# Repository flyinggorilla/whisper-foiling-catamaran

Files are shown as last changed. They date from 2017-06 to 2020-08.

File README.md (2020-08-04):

# Whisper Foiling Catamaran sailing experiences

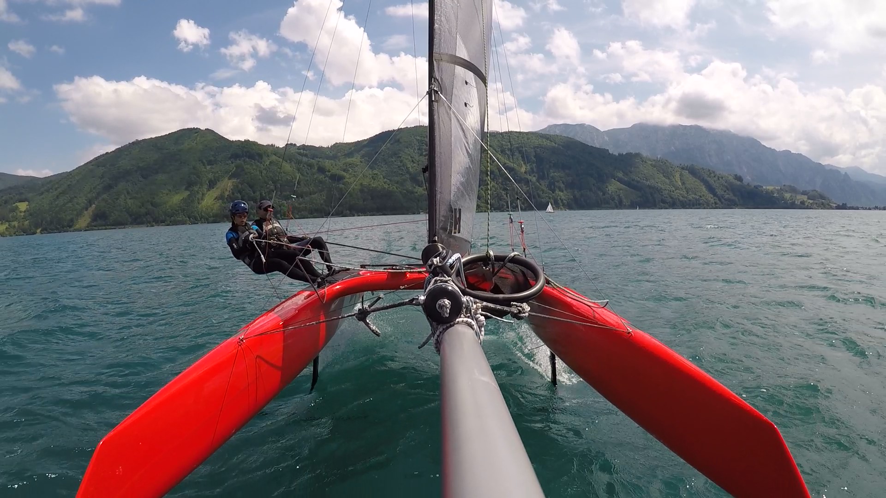
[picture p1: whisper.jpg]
whisper (https://www.youtube.com/channel/UCwhb6u4A_Hy-c-eJbMLW7bg)


# YouTube Whisper Foiling Channel
[YouTube videos](https://www.youtube.com/channel/UCwhb6u4A_Hy-c-eJbMLW7bg)

# Repairing and tuning the Whisper with 3D printed parts
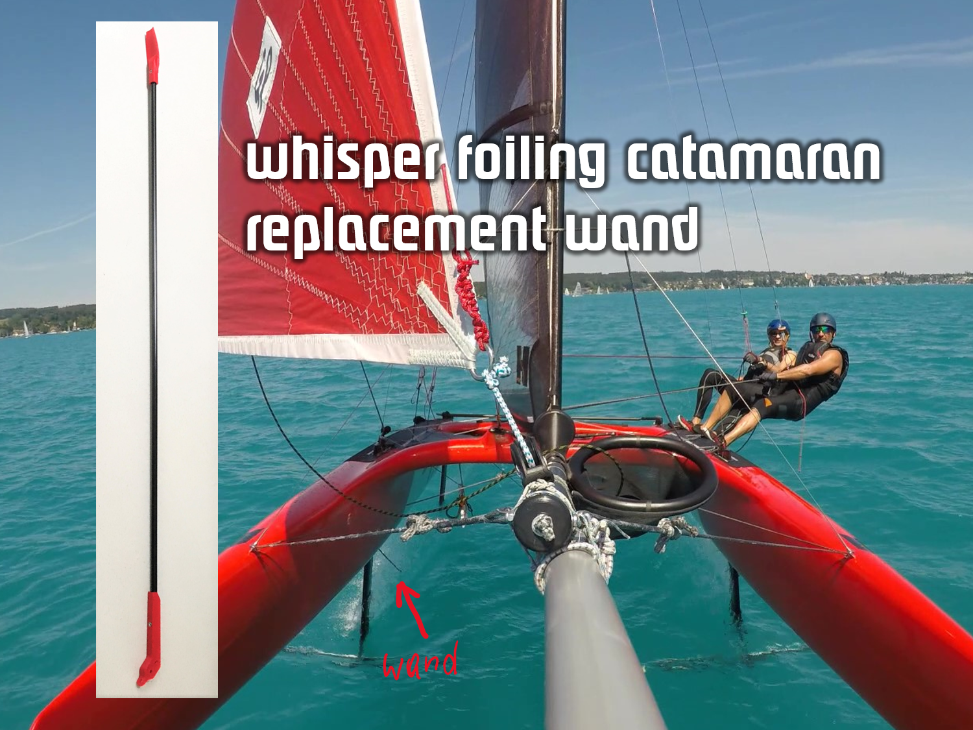
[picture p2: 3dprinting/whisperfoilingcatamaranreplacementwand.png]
3D printing

[3D printed models](3dprinting)

# rigging and trimming tips
## main sail 
O-shackle should be placed in a way that the knot shows towards the mast. This is needed so that the main halyard unhooks easily when rotating the mast 90 degrees.

## foils
Flaps should show 2-3mm upwards when the wands are down.

## Fastest sailing when sail is above one
Async setup of flight height through ride-height adjuster wheel and through foil rake, like 2.5 windwards and 3.5 leewards. 

Foil rake: 4 is absolute max. 2.5 to 3.5 is good.
(Update: I sail in freshwater, which has less density, so I use foil rake at low winds asymmetrical 4 windwards, 5 leewards. When foiling single-handed upwind I go extreme 5 leewards and 2 windwards)

Whiteformula hints: Straight line speed is best upright, but sailing for an upwind mark is best at 15degrees over to windward, this way you will generate lift towards the mark. 
There is no need to adjust the ride-heigth with every tack to achieve the 15 degree angle, just async foil rake and balancing the boat with main sheet should do it. 

## Tacking
I found tacking actually quite tricky with the Whisper vs the Nacra F16. The Whisper barely turns through the wind.
When sailing alone, I keep my weight as far back as possible to turn the bow through the wind. If that doesnt work, whats common, I push the main sail by hand into the wind so the boat gets additional turning momentum.
When sailing with crew, the crew back-winds the jib. However, even this didnt allow for quick tacking. 

The quickes tacking so far is a __semi-foiling tack__. So while on the foils the helm and crew move from trapeze onto the boat. It just needs a little losening the main-sheet and the whisper remains remarkable stable. So then its all about speed of unhooking the trapeze, and turning the boat into the wind while still on the foils. So far we managed twice to turn the boat through the wind. But by then we lost too much speed and went gently off the foils. However, we did the tack in the so far speediest form I know of.  

# boat tweaks

## pressure compensation piece
I modified the hatch lid to have a pressure compensation piece. That is water tight, but also allows air to flow, so that the hull is pressure compensated. I used the Bopla 12mm DAE, one of many vendors. https://www.bopla.de/fileadmin/products/_Product_Information/52042000-spec_DAE_M12_Technische_Information-EN.pdf

pressure compensation

## foot straps
Foot straps are great. No need for a chicken line on downwind course. And especially when single-handed trapezing with gennaker its for me priceless. Yes there is some insury risk, but so far I had not a bit of an issue, as the whispers wavepiercers carve so gently through the water so that you are not thrown off as with a regular catamaran (like my previous F16). I mounted it just about 3 centimeters away (aft) from the internal hull structure you can see when you take a picture with your phone camera from the inside.
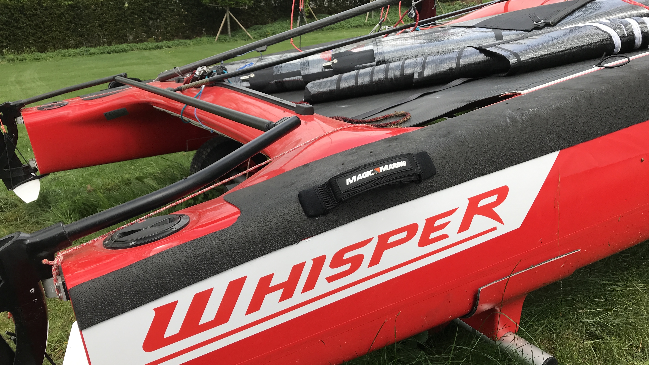
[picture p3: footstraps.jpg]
footstraps

I bent washers to approximate the hull shape and used sealing glue to tighten it 4 screws per strap.

## chicken line
Update: I no longer use the chicken line, as i mounted footstraps. 

So far all of the capsizes and most of the splashes were related to losing balance on the boat. While I hope to get better at keeping balance and steering the boat smoother, I still need to be able to hold-on to something. The traveller line isnt ideal, as the traveller cleat opens to easily and when the traveller is a bit out, you pull the sale all the time. On my Nacra 16 I had a chicken-line, which saved me a couple of times from capsizing when sailing gennaker downwind. So here is my first implementation of a chicken line for the whisper. Its good, it works, and it could be further improved too.
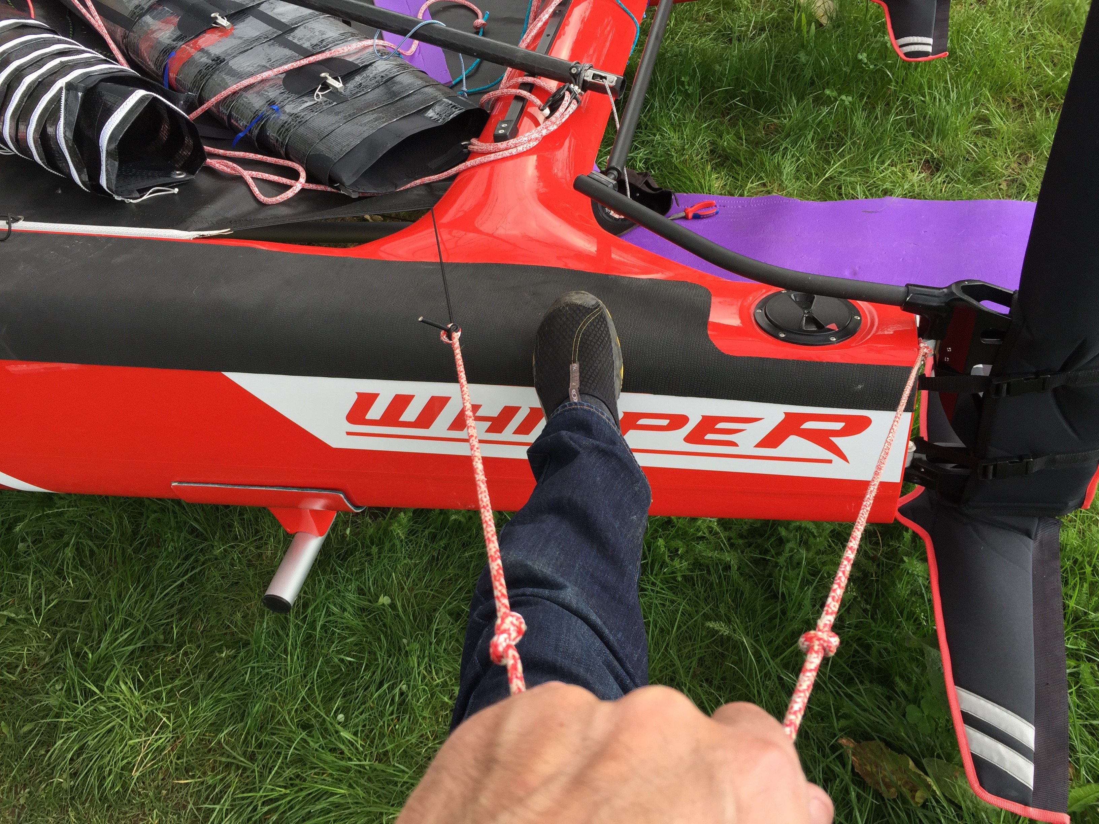
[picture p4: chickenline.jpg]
chicken line


## hull lid marks
Trying to be a "good customer" I followed the advice to untighten the hull-lids - just a little bit by a half turn - so that the hull can equalize air pressure. However, on my third sail with this boat ever, I didnt notize during the pre-sail check that I forgot to tighen it. The lids were on, but just not tight. During a later capsize I lost then one of the hull-lids and flooded one hull with water. The Whisper almost sank and needed some rescue help. So to avoid this from happening ever again, I put a marker on the hull lid, so one can easily see whether its tight or not.
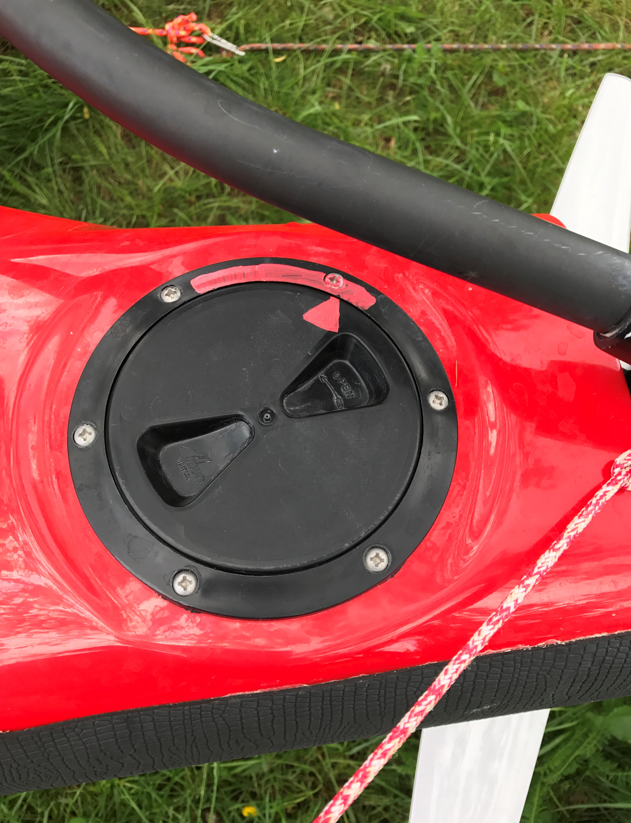
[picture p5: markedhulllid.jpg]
hull lid marks


## 4-wheel trolley
So I do need a 4-wheel trolley to slip the whisper. The air-filled wheels swim nicely. But also they swim nicely, so risking to damage the foils when sliding the boat onto the trolley. So the best fix for this was to fill the rear wheels to almost 100% with liquid. The front wheels got only 50% liquid, so they would still swim, making it easier to keep it in contact with the hulls. I found from the camping area ecological frost proof liquid that is used for camping cars. It felt I filled the old airpump 1000x with that liquid and pressed it into the tyre. But it worked.    
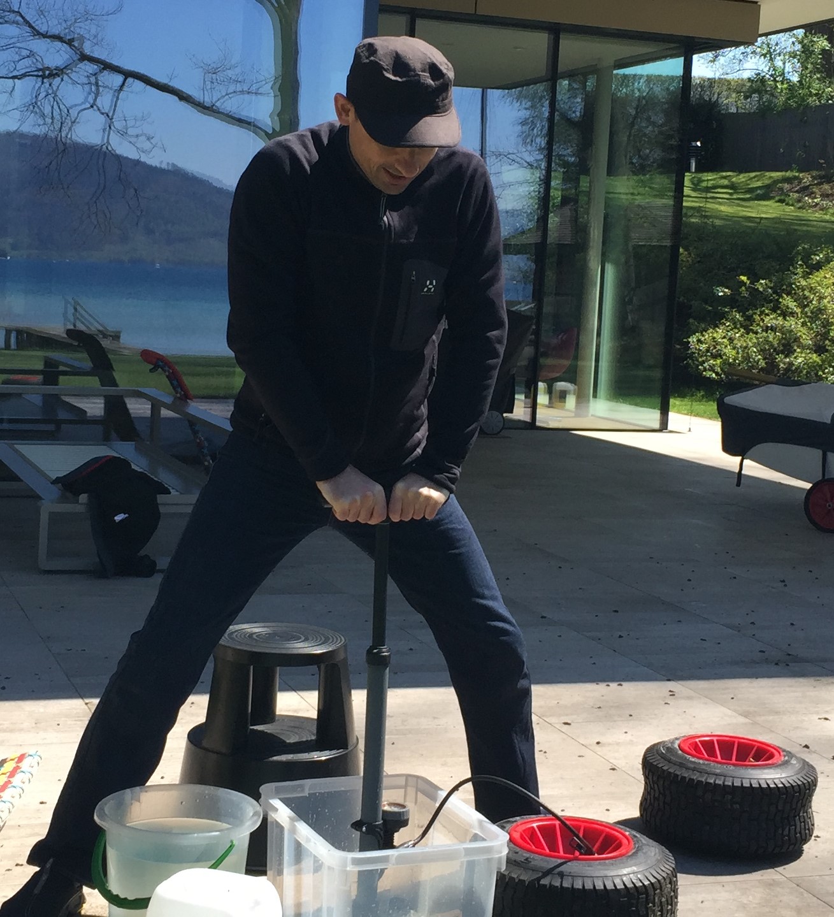
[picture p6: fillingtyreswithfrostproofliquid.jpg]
Sinking wheels

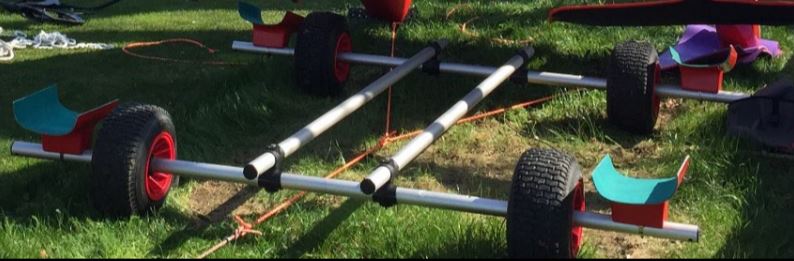
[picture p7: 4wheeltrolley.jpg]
4 wheel trolley


## slipping line
I do slip boats with a winch. I found the best way to pull the Whisper is a dyneema line from the gennaker shackles on each side of the boat. I put a "cleanup" expansion cord in there so its not loose during sailing. slip line

## sacrificial halyard - no longer
At the very first day with the Whisper we lost the jib halyard twice, requiring to pull down the mast. Also I wanted to minimize the amount of work to (de-)rig the Jib.
My solution for this is to have:
* 1.8mm line, about 2m longer than the original sacrificial halyard.  
* tied on one end to the halyard eye
* tied on the other end to my abovementioned slipping line
So when hoisting the Jib, everything stays tied. I simply flake the new (non-)sacrificial halyard and stow it in the trampoline bag. Again, with all knots in place.

Picture shows the (non-)sacrificial halyard tied with a mini-carabiner (not required) to the slip line. 
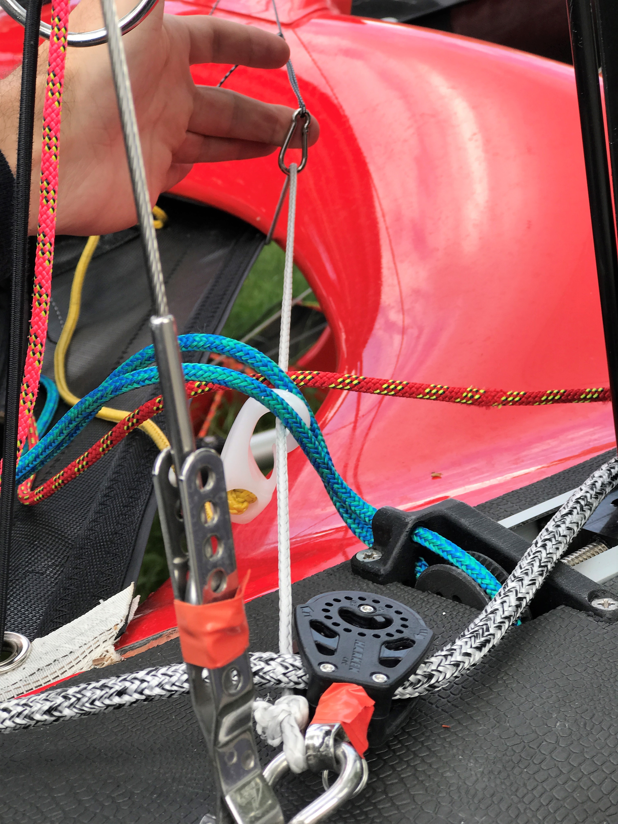
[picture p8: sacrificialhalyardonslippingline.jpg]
sacrificial halyard on slip line


## rigging tension 
Tightening and loosening the rig at the stainless striker with the spanner wrench is somewhat annoying. 
I am a lazy person - in the sense of repetitive tasks - and hence want to automate everything as much as possible.
So I have ordered a 17mm spanner ratchet and let you know how much of a help it is.
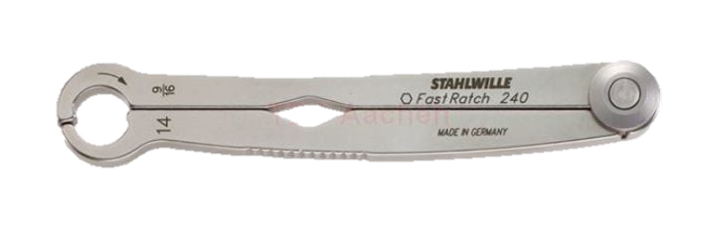
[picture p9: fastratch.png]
fastratch


The Whisper manual says it should be 17 Loos gauge rigging tension. I justs bought a more modern spinlock from rig-sense. There is a [conversion table to loos](https://www.spinlock.co.uk/uploads/files/042018/5acf32f42921105789bbdb1f/original/Spinlock_Conversion_Chart.pdf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) so my mast support rig with 120kg / 21loos should be fine.

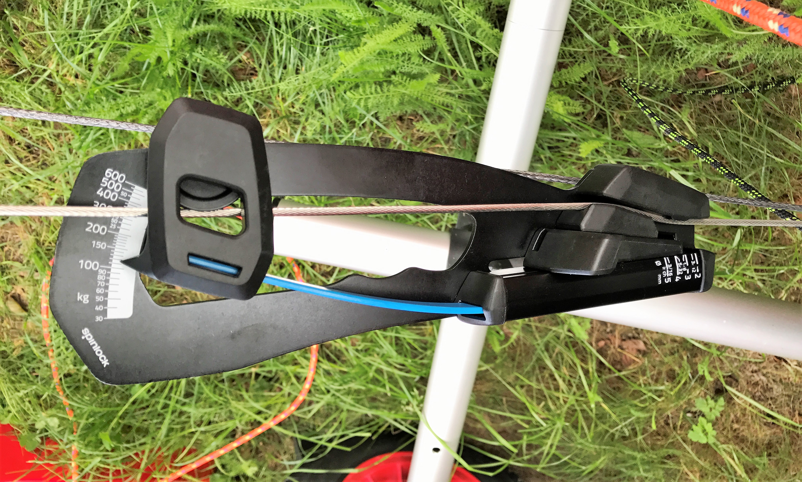
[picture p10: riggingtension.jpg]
rigging tension diamond


Here are some measurements of status quo measurements. I am interested in the appropriate target settings...

| Line | Tension in kg | Loos gauge PT1 (approx.) | comment |
|---|---|---|---|
| Mast support at spi pole 3mm | 160kg+ | ~25  | measured below spi pole |
| Mast support V-wire 3mm | 80kg | ~17 | (V-wire) measured under trampoline, is always half of measured below spi-pole - recommendations seem to be Loose Gage 17 absolute min, 20 light winds, 25 heavier winds on Loos gauge |
| Shrouds 3mm | 80kg  | ~17 |  |
| Diamond 3mm | 125kg  | ~22 |  Should be more Loose 30, which is more 220kg |
| Diamond pre-bend | ~50mm | | measured distance from mast to hypothenuse of triangle |
| Jib | 70kg  | ~15 | measured above stainless striker |

### mast safety line
In order to avoid the mast falling accidentally when untightening the rigging tension at the stainless striker, I put a short piece of dyneema rope there. I am lazy and thats more convenient than tying the spinnaker halyard back and forth to secure the mast.
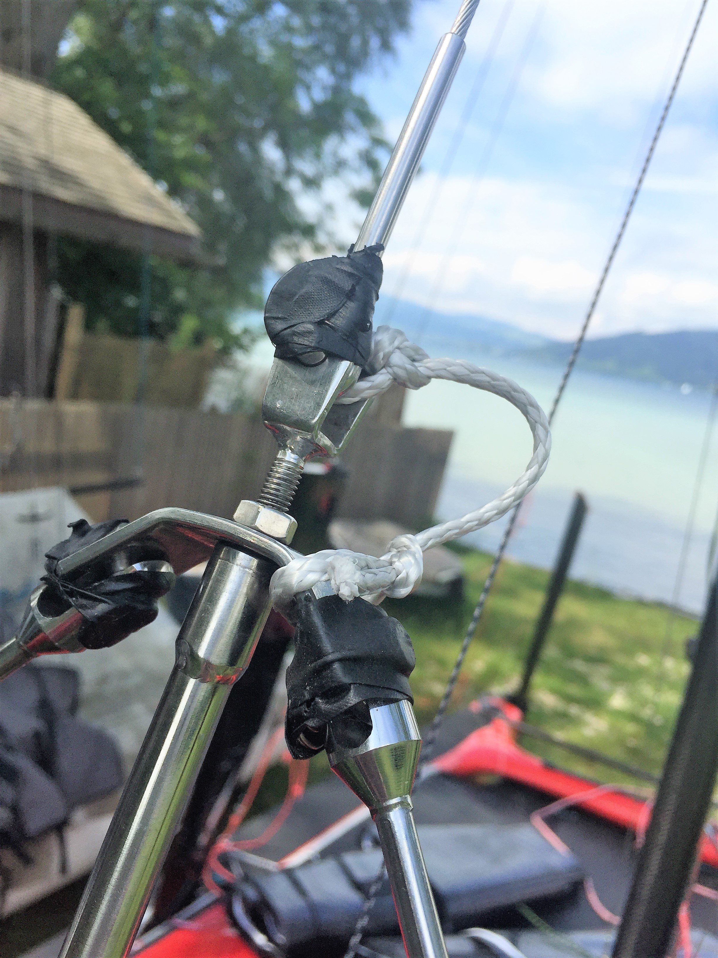
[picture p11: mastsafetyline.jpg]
mast safety line


## ride-height adjuster
I got my stunning looking new black foils and opened the sailing season with them. During one of the first sails I discovered that the ride-height adjustment wheel got looser the more I turned it back and forth. I was worried the mechanics fall apart while on water. So I aborted the sail and took the ride-height system on land apart. The issue was the the **nut on the threaded rod was loose** (see picture below the not on top of the red T). 
I checked the position of the nut so that the 3D-printed wheel would fit nicely, marked the position, and put then __threadlocker glue__ on it to make sure it wouldnt move again. So far it works well. 

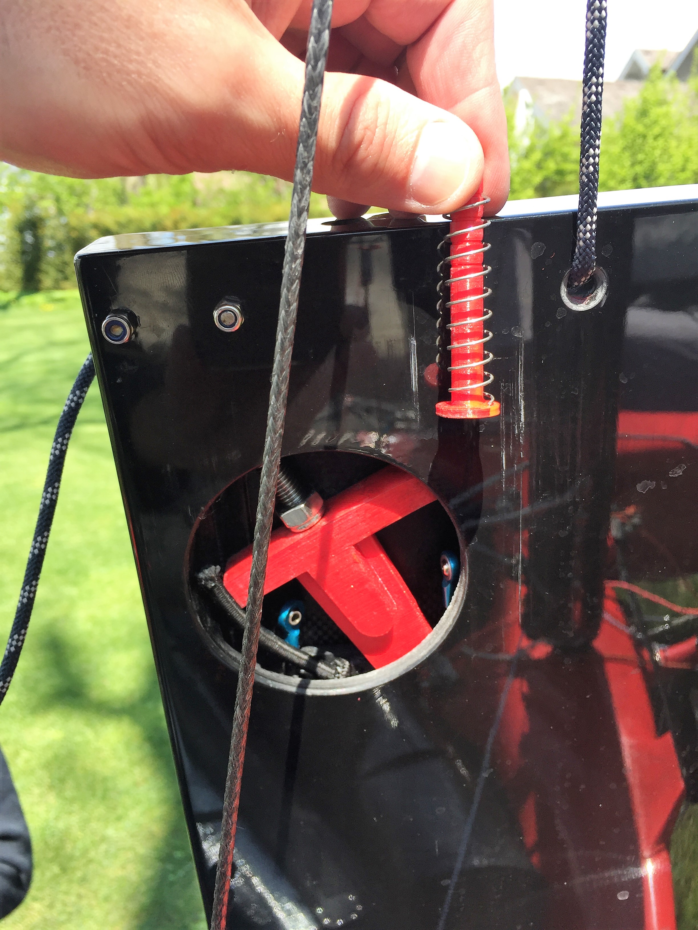
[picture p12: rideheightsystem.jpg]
ride-height system


## righting line
Yes, it costs a few grams, but its less stressful if you have a righting line that you can pull out of the pocket vs. making knots into the gennaker sheet for uprighting. The other benefit is that the crew can use it to hold on when the helm is working the main sheet. 

## main sheet pulley

### 1) two-handed
There is quite some force on your hands when constantly operating the main sheet to balancing the boat on the foils. So I ordered 40mm Harken blocks that allow for a 6:1 translation vs. default 4:1. I also ordered a variable thickness main sheet and need to splice it on the block properly so to not destroy the original pulley. I will let you know how it goes.

6:1 pulley

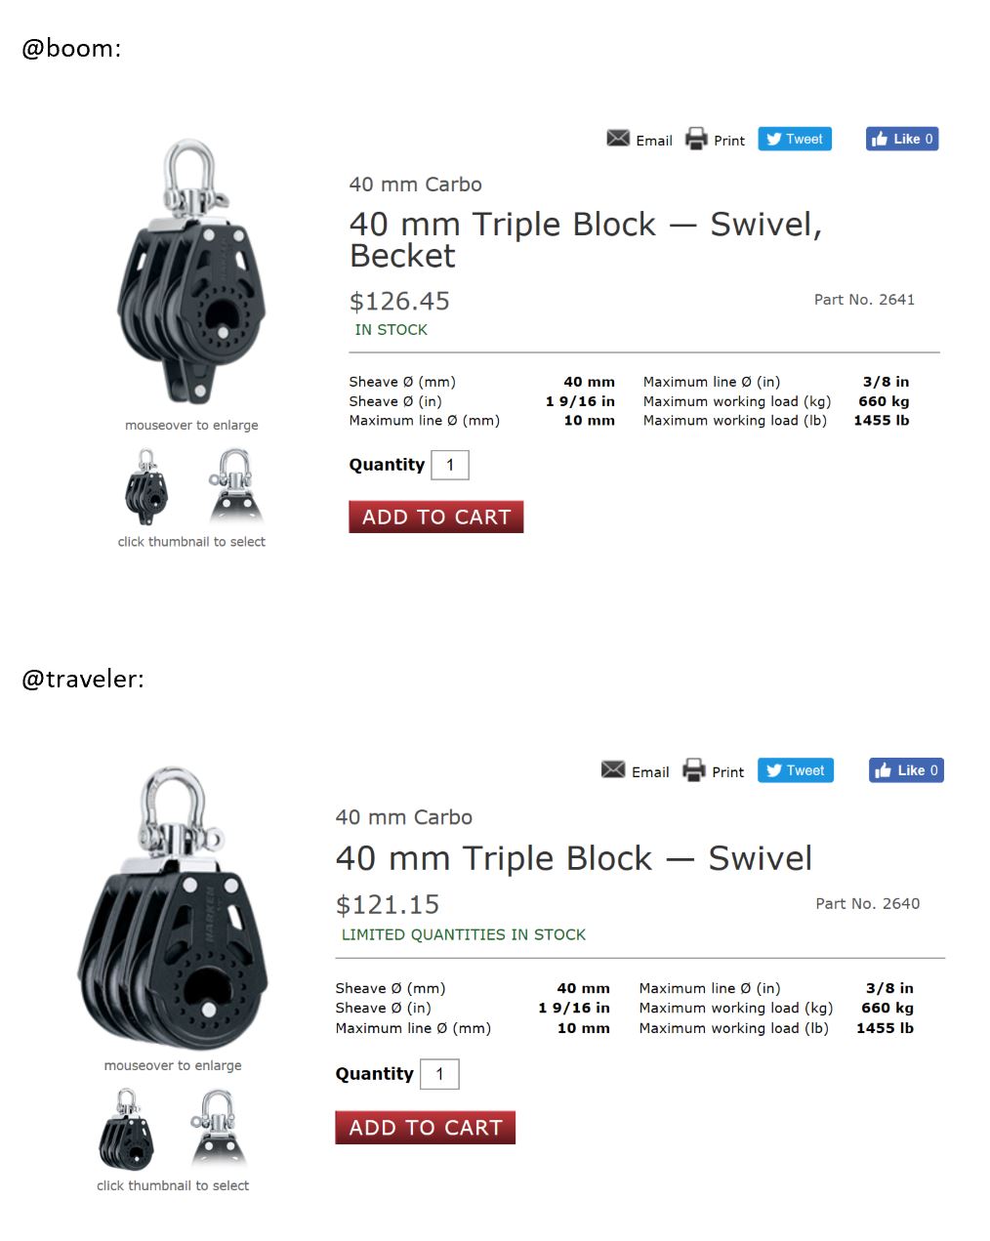
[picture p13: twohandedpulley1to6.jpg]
Harken blocks for two handed 1:6 purchase system


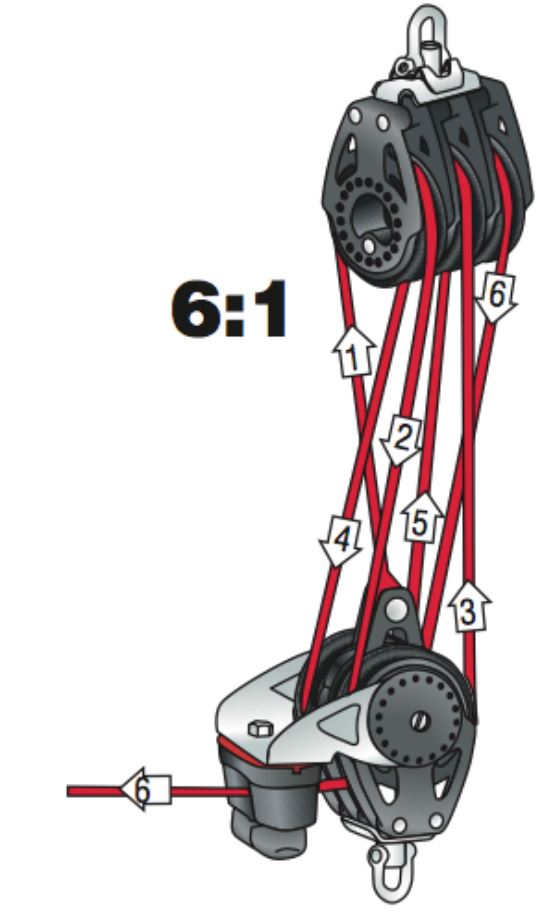
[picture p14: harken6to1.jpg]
harken 6:1


### 2) single-handed
There are two issues making single-handed sailing more difficult. 
* One is that the main-sheet location at the boom,pulls you forward, which makes it hard to balance when you are already hiking at the very end of the boat. 
* Second, managing the gennaker sheet, main sheet and tiller all at once is one thing too much. At the Nacra i could cleat the main sheet while hiking and operating the gennaker.

So the idea is to solve both items with a set of following Harken blocks. I had to take the larger 57mm blocks because the cleats that fit the original block size would only handle 6mm lines, what is too tight for main sheets.
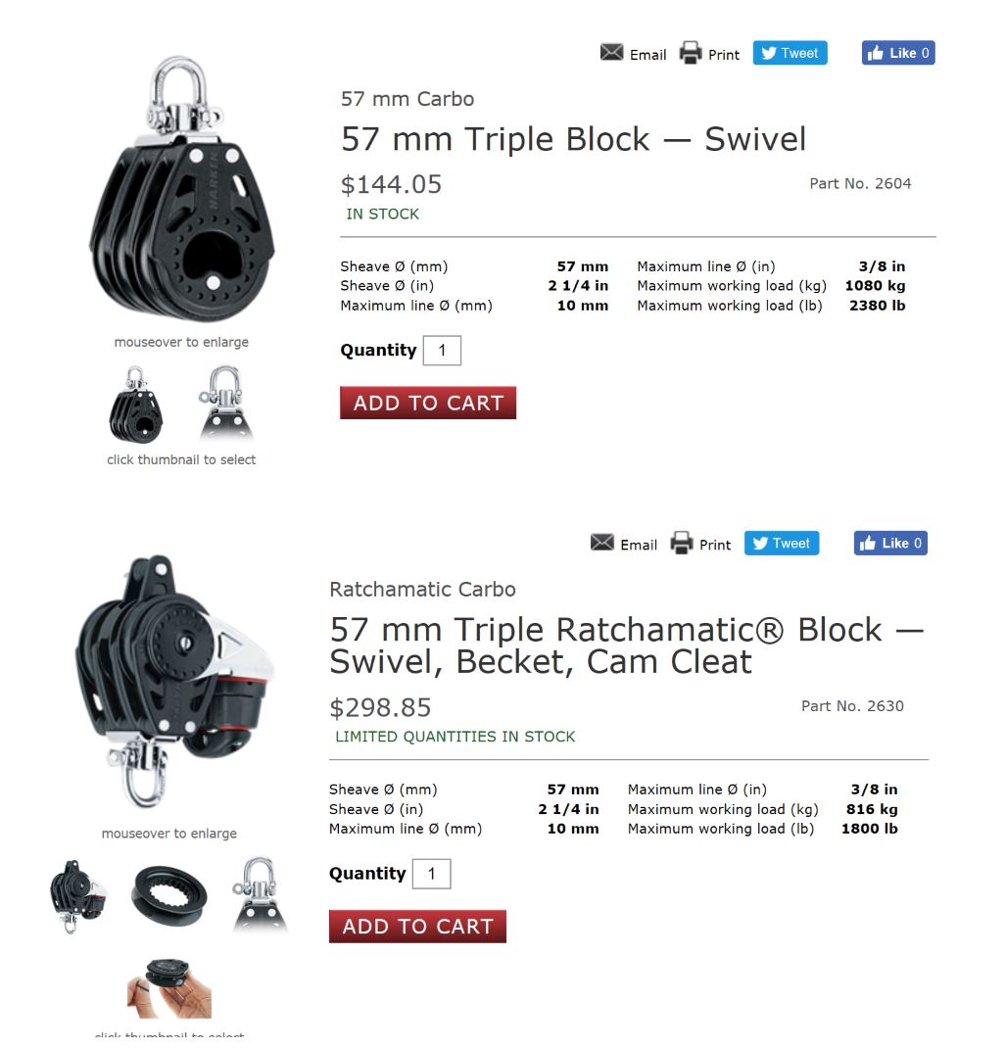
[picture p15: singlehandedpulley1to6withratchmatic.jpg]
Harken 57mm blocks


Yet to be tested.
 
## gps
Having the only whisper at this lake is cool, yet suffers from the ability to match-race. So I need to know the speed on the go, to get a better sense what works. So far my conclusion is that proper boat balance has more impact than sail trim of jib sheet, mast rotation, cunningham. However, I am sure I still need to learn a lot.
So I mounted a Velocitek SpeedPuck. 
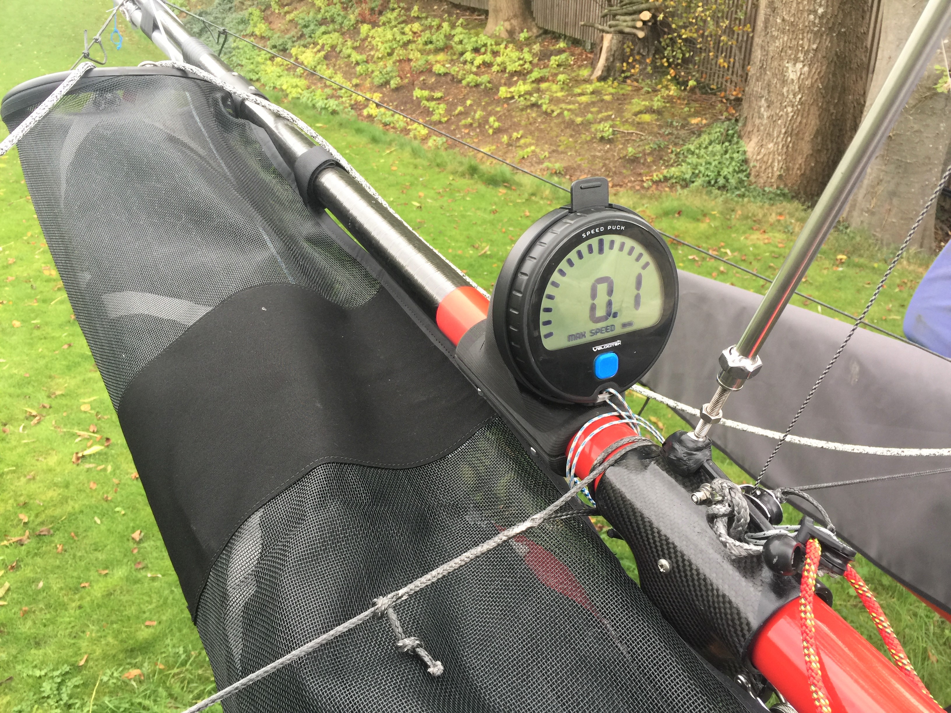
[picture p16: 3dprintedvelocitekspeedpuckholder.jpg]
Speedpuck mounted on Whisper spinnaker boom

The holder is 3D printed and can be found here [https://www.thingiverse.com/thing:1814601](https://www.thingiverse.com/thing:1814601).  
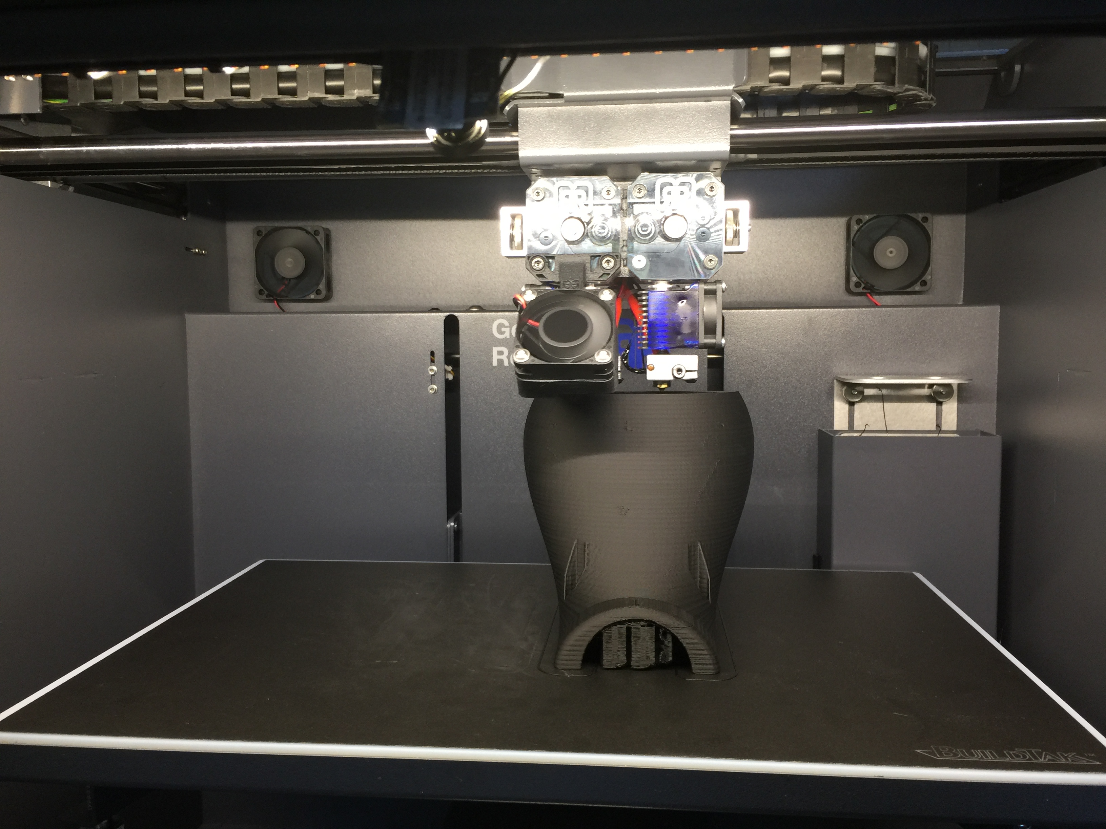
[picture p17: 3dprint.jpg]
3d printed holder


## rudder holder (v1 sucks, better move on to v2 below)
Launching the boat in shallow water requires to hold the rudder in position by hand. When sailing single-handed its impossible to pull the boat at the bow through the water and hold the rudder at the far distant end of the boat at the same time. so something needed to keep the rudder a quarter-height down. I had this door wedge at home, and squeeze this at the side of the rudder to keep it at height. This works ok, when pulling the boat, but as soon as you are on the boat and pick up speed, it falls off as the rudder gets lift. Yes, if you manage to better adjust the angle of the rudder so the force goes down, maybe its possible to better keep it in place. However, I had to dive for the wedge already and since added a line to it.

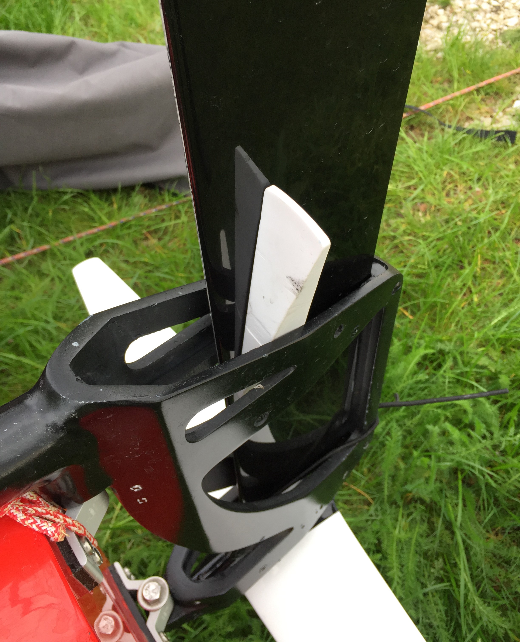
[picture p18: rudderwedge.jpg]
rudder wedge


However, it works only when there are no waves. Waves push the rudder up/down and the wedge falls immediately off. Has anyone a better solution?

As alternative I am thinking about a rope from the T of the foil to keep it up, and another rope from top of foil to keep it down. Maybe 3D print a little piece that makes that easy. So the work on a boat never ends...

## rudder holder (v2 works great)

For coming in/out of shore in shallow waters, I needed a simple solution for keeping the rudder in middle position. One of the issues with my previous "door wedge" solution was that it failed when a wave or simply the foil-lift at speed pushed the rudder up. So the solution needed to keep the rudder in place - up and downwards. Also it should be easily adjustable on the water, without needing to change knots or using tools. So I came up with this simple solution that everyone can 3D print. You need a 3mm rope, a simple plastic carabiner, a 5mm bungee and one or two pieces of those "rope twisters" as I call those 3d printed parts - per rudder you want to equip with this.  
Here is the link to the rudder holder 3D print piece https://www.thingiverse.com/thing:2426782. 

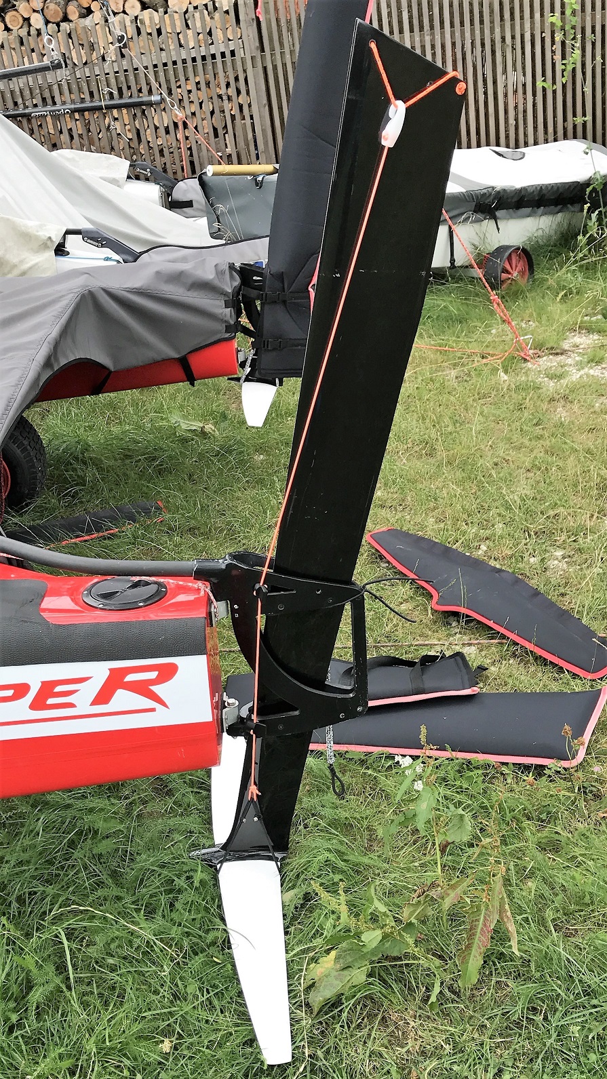
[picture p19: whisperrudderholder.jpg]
whisper rudder holder v2


## repairing the wand

ordering a replacement wand from whiteformula is no problem and reasonable priced. however, as I like to be able to fix things right away and tinker around too, I printed my own wand parts. Ordering carbon rods is no problem too, they are about €10 per piece. 

I have uploaded the [CAD and 3D print models here...](https://www.thingiverse.com/thing:3054149) 
3D Model (https://www.thingiverse.com/thing:3054149)

## how to remove water from the mast
The mast should be water tight. But however, in my unfortunate case when I lost the lid of the hull and the boat almost sank, I did get water into it. The entire mast was in the water and it could have gottin in at the foot or somewhere else on the mast. Usually when capsizing the foot is above water, so less risky for untighteness.

However, in case you have water in the mast, I had gotten from whiteformula's Tom White great hints. To get it out you can remove the screw from the halyard turning block eye. Near the base of the mast. This should let out any water. Note, the smaller upper-one screw of the two is connected with the hollow area of the mast, so this one lets water come out. 

drain water from mast foot

If this does not solve the problem it is most likely that one of the rivet plugs is leaky. You can remove the white plastic plugs in the rivets on the mast hook. You can either pull them out with a pin or you can remove them with a 2.5mm Drill bit. I got some plugs from the nice guys from whiteformula.

drain water from mast top
 
A very easy way to find the leak is to put soapy water over all of the rivets and blow air into the mast through the halyard eye hole using a bike pump. You will see bubbles come from the rivet that is leaky.
 
If it is not a rivet but a screw in the foot, you can remove the screw, put a little silicone in the hole and then put the screw back in. That should solve it.

## water in the hull
Recently, when checking the hull lid, i figured my whisper has water in the hull. I dried it up and after the next sail I had again about half a litre in each of the hulls. Since i didnt capsize i figured the problem must exist on both hulls. So with the lessons learnt from sealing the mast I used soap-water on the outside and my electric airpump (low pressure, vacuum cleaner like pump with 2000l per min throughput) to put a little pressure into the hull. And voila the bubbles revealed that both of the rudder fixings were no longer tight. 
untight rudder mount
According to whiteformula does the urethane based sealant on the pintle always work loose after a while. So this requires re-sealing every year as the load on the transom is very high. 
So I sealed it with flexible silicone and will see how long that lasts. Right now the hull is watertight again.

# some stories...

## swimming for screw-driver
It is not the worst, but still this is what you don't want to happen. Especially when single-handed sailing you are toast. 

So recently we went out, had a great sail. When approaching the shore and stopped to prepare for slipping we couldnt lift the backboard foil anymore. We double-checked the boat speed, but it was zero. So was the wand blocked by a branch or so? Nothing there that we could identify from the trampoline of the boat. Big problem, because it means we cannot pull the boat to the shore due to shallow knee-deep water. 
So we tied the bow to a closeby buoy and I jumped into the 14 degree celcius warm (!) water perform a closer inspection. Then i could feel it with the fingers. There was something on the back side of the foil preventing to lift it. Swimming to the inside of the hull and diving  the head underwater I could see that the screw was loose. Since I usually don't bring my tool-chest on-board flying, I had to take a swim and get a screw driver.Screw tightend and the foil went up again. Phew. Somehow at the end I broke the wand. How that happened is unclear to me. It just broke by a simple touch. Maybe the wand was already damaged during the ride by only being half mounted.
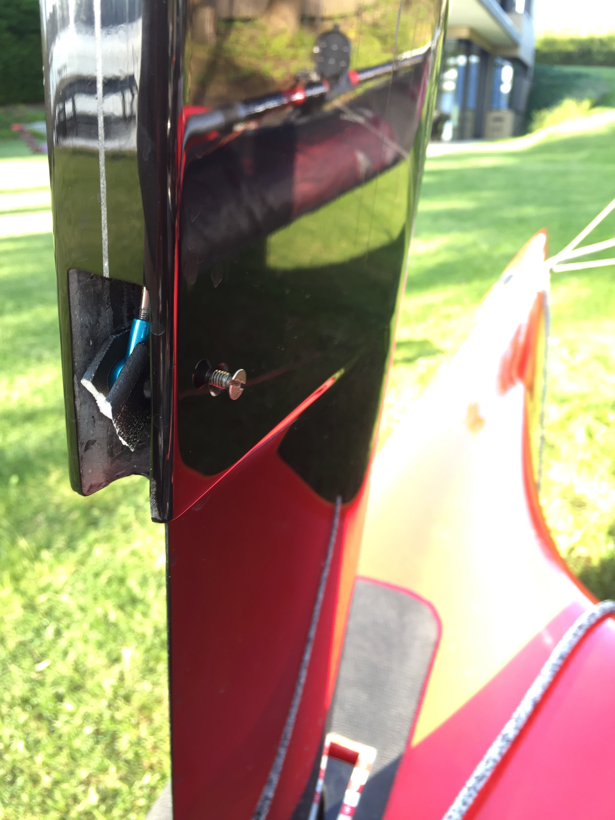
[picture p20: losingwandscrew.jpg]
losing the wand screw


So the boat and crew was rescued and we could slip the boat on land. Gladly I had ordered spare wands with the boat so I was on to fixing that broken one. It was trickier than I thought. The connecting metal axle had to be unscrewed at the top of the foil as well as at the wand. When I had finally the new wand in position, I figured the 3mm screw wouldnt go in. Why? There were no threads. So fortunately I had 3mm thread cutting bits. They come as a set of 3 and I used only the first two, so that the threads would be tight enough and keep the screw in place.

As to the larger screw that I almost lost during sailing, I used silicone glue, which should allow me to open the screw again in the unpleasent event i crack the wand again.

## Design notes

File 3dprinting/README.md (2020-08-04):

# Repairing and tuning the Whisper with 3D printed parts
3D printing

* [__wand system__](#Wand-System) to replace parts that break with easier access as well as tunings
* [__ride height adjuster__](#Ride-Height-Adjuster) much easier than the rope, with up/down indicators
* [__rig tension adjuster__](#Rig-Tension-Adjuster) stainless striker hand-wheel
* [__rudder holder__](#Rudder-Holder) to lock in various heights in shallow waters
* [__speedpuck mount__](#Speedpuck-Mount)

community contributions:
* [__boom holder__](#Boom-Holder)
* [__dolphin striker line guide__](#Dolphin-Striker-Line-Guide)

# Wand System
The [Whisper foiling catamaran](https://www.youtube.com/channel/UCwhb6u4A_Hy-c-eJbMLW7bg) uses "wands" as ride height sensor to dynamically control the foil lift. Parts of that wand system break from time to time, so printing them yourself can be convenient.

To produce an entire wand, you do need:
--------------------------------------------------------
* carbon rod (CFK) 8mm diameter, 1m length (you will need to cut it to 830mm length)

* 3D print paddle (lower end)
* 3D print arm (top part of wand)
* 2 stainless screws (3mm x 10mm or longer) -- you will clip to proper length anyway

Print material needs to be stronger than PLA, so I use e.g. ASA instead..

additional replacement parts related to the wand system:
--------------------------------
* lever inside of foil ride height mechanism

### Updates:
* 20180826: updated wand arm to mount the rod screw from the side
* 20200530: added wand paddle/skimmer model with screw mounting from aft
* 20200530: added wand paddle/skimmer model with screw mounting side - maybe thats the most convenient option for mounting. 
* 20200606: added wand arm version to mount the rod screw from aft, and another version to mount the screw from both sides, to make unmount/mounting easier. mechanically is the version from 2018 with one rod screw from side more robust.

## wand arm:
* use 8mm drill to create a snug fit of the rod into the 3D printed parts
* drill 5mm hole for the shock cord that pulls the arm back
* drill 4mm hole for the hinge
* drill 2.5mm holes for the metal connector, and cut a M3 3mm metric thread into it 
* drill a 2.5mm hole into the carbon rod for the 3mm screw (I use a HSS-cobalt drill for the Carbon rod)
* clip the screw to a length so it just doesnt stand out on the other side of the arm

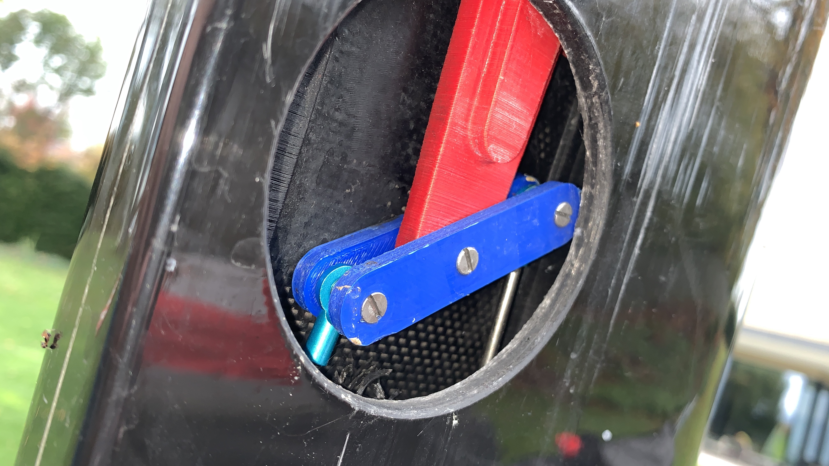
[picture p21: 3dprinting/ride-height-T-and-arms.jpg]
arms

note: picture shows original whiteformula printed red T-part which was printed standing. thus you see the printing layers. this part will break easily therefore. read below how to print stronger T-parts. The blue arms are printed with strong ApolloX ASA material.

## wand paddle:
* use 8mm drill to create a snug fit of the rod into the 3D printed parts
* drill a 2.5mm hole for the 3mm screw (I use a HSS-cobalt drill for the Carbon rod)
* clip the screw to a length so it just doesnt stand out on the other side of the paddle

## wand rod:
* total length of original wand including arm and paddle is 930mm
* cut the carbon rod to 830mm 

## wand ride height lever:
* drill 2.5mm holes for the 3mm screws (I use a HSS-cobalt drill for the Carbon rod)
* drill 2.5mm holes for the connecting rod
* cut M3 3mm metric thread into it -- you might use only 2 of three cutting tools, so that the fit of the screw is tighter
* a tiny bit of glue helps additionally to lock the screws, so they dont open accidentally 

## wand T part:

This is a replacement part for the Whisper foiling catamarans ride height T part. It is printed laid down so to benefit from increased strength vs. the original part. As a tradeoff, it needs to be printed with supports.

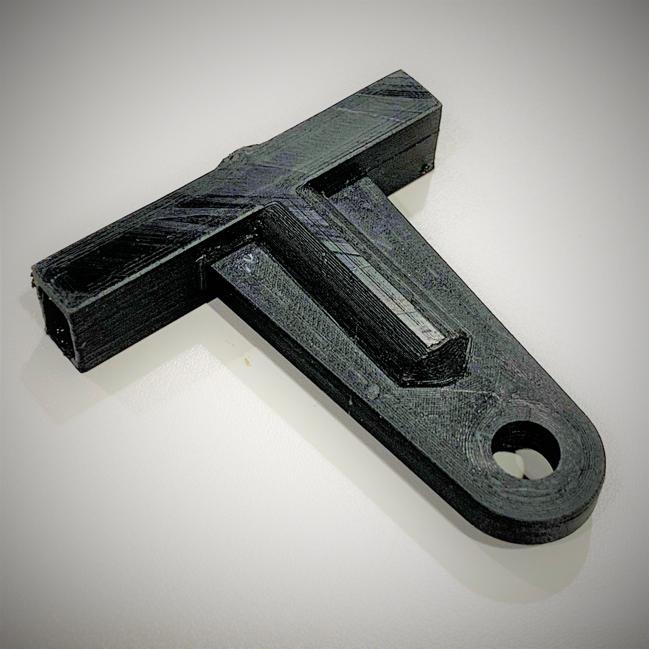
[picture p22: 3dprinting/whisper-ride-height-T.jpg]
T part

[T part](whisper-ride-height-T-with-threads.stl)

I recommend printing in FormFutura ASA (ApolloX) material, which is UV, warmth and water proof. To make sure it is robust enough it is super important to print it horizontally with supports and not standing.

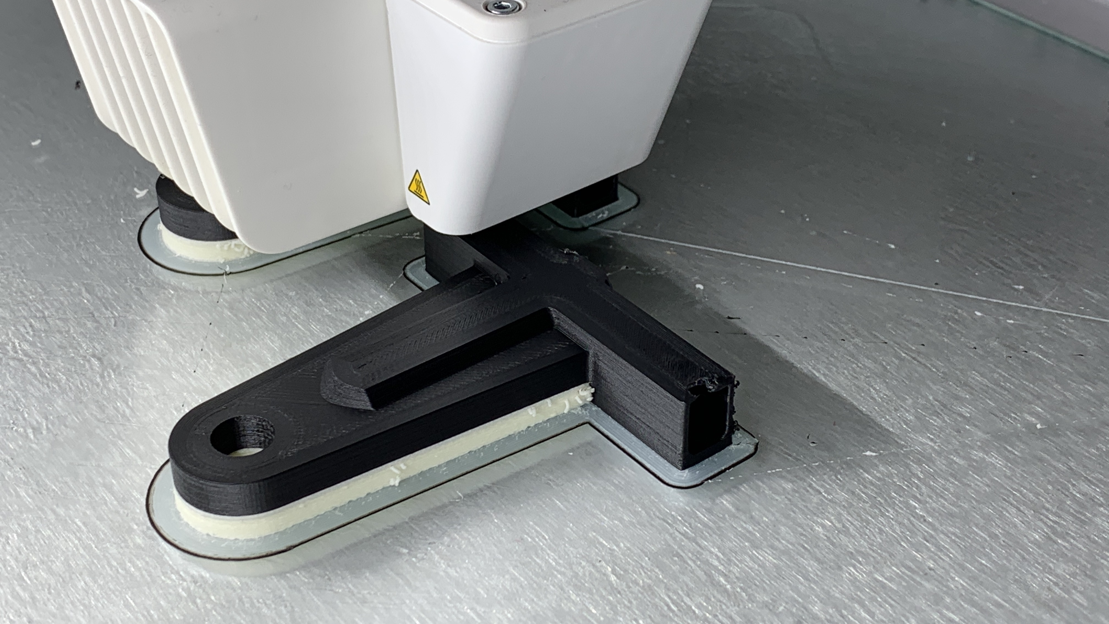
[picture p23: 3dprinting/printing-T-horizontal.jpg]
horizontal printing with supports


## Pins
Contributed by [Christian Witsch](https://www.youtube.com/channel/UChSlq1hUahmVQtAV6N_KJtA)

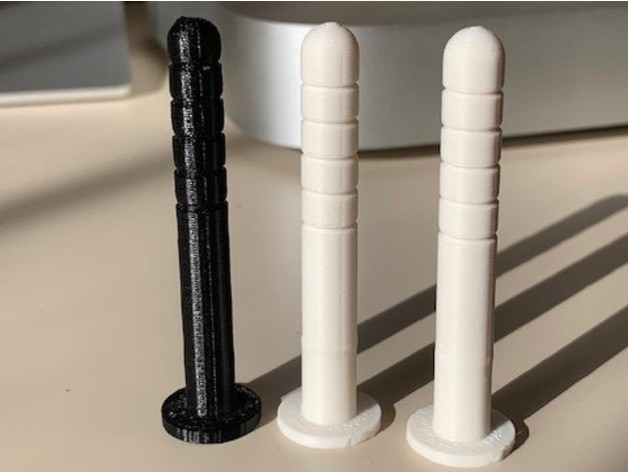
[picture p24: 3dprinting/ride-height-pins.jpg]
ride height pins


[ride height pins](ride-height-pin.stl)

## Lever Arms:
* drill 2.5mm holes for the 3mm screws
* cut M3 thread into 2.5mm holes (hint: using only 2 of three cutting tools, makes the fit for the screw tighter so it doesnt get lose as easily; a tiny bit of glue helps additionally to lock the screws)

## T-Part
This version does not use a metal thread insert as the original one does, but instead receives the threads directly in the plastic using an M8 thread-cutting tool. So please check out print settings below, as those are unusual yet important for robust threads.
* supports from bottom up only (no supports for the M8 hole needed)
* make sure its printed horizontally
* i recommend approx 2.8mm shell/roof/floor
* M8 thread cutter
* use a 9mm drill to just clean-out the 9mm hole for the arms

There is also a version with Stainless Helicoil metal insert. It do believe it is not required as printing ApolloX ASA in horizontal layers provides enough strenght. In case you still want the metal insert, you will need M8x1.25xD3 Helicoil kits like [this](https://www.amazon.com/Rocaris-Thread-M8-x1-25mm-Compatible-Repairing/dp/B07F18GHZG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) and long enough stainless helicoils. 

threads require enough material around them:
* shell: 2.8mm 
* roof: 2.8mm
* floor: 2.8mm

make sure to use robust infill patters. with the 3d octo pattern it works with 50%
* infill: 50% 

supports: 
* from build plate only
* when using dual-printing with water soluble material then FormFutura Helios (PVA) works best with ApolloX (ASA).

build plate: 
* temperature: 90 degrees
* adhesion: DimaFix applied to glass-plate

## 3D models
you can download from Fusion 360 site  in a format of your choice

* [wand paddle - screw forward - fits original rod](https://a360.co/2O1Cxfj)
* [wand paddle - screw aft - easier to mount](https://a360.co/3i54MJ1)
* [wand paddle - screw sides - easier to mount](https://a360.co/3gtzBqt)
* [wand arm](https://a360.co/2wckjRI)
* [wand ride height lever](https://a360.co/2w9MqAS) 
* [T Part Fusion 360 CAD Model](https://a360.co/36usnOo)

# Ride Height Adjuster

The Whisper catamaran has a ride height adjuster, that is intended to be controlled with a 4mm rope. However, as I - and most Whisper users to my knowledge - dont use the rope but adjust the ride height manually, I figured lets make manual adjustment easier.

Hence here is the ride height adjuster that also has a little imprint to help with turning left means higher ride height and turning right means lower ride height. It replaces the original ride height wheel.

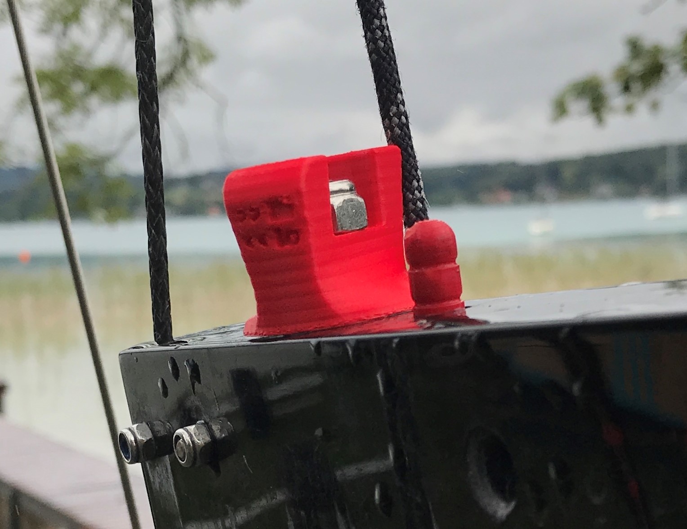
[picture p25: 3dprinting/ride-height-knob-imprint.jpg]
ride height knob


I printed with UV resistent ASA (FormFutura ApolloX) filament.

Here is the model [https://a360.co/2NASVn5](https://a360.co/2NASVn5)

# Rudder Holder

For coming in/out of shore in shallow waters, I needed a simple solution for keeping the rudder in middle position. One of the issues with my previous "door wedge" solution was that it failed when a wave or simply the foil-lift at speed pushed the rudder up. So the solution needed to keep the rudder in place - up and downwards. 
You need a 3mm rope, a simple plastic carabiner, a 5mm bungee.  

whisper rudder holder v2
[whisper rudder holder v2](WhisperRudderRopeStraightTwister.stl)

# Speedpuck Mount

This is v4 of a mount for the Velocitek Speedpuck on the Gennaker pole with 44mm diameter like on the whiteformula Whisper foiling catamaran. Its designed to ensure that sheets dont tangle up. v4 stl files are printed 30% lighter in weight, yet more robust when printed with hexagonal infill. also the 5mm screes fit now easier.

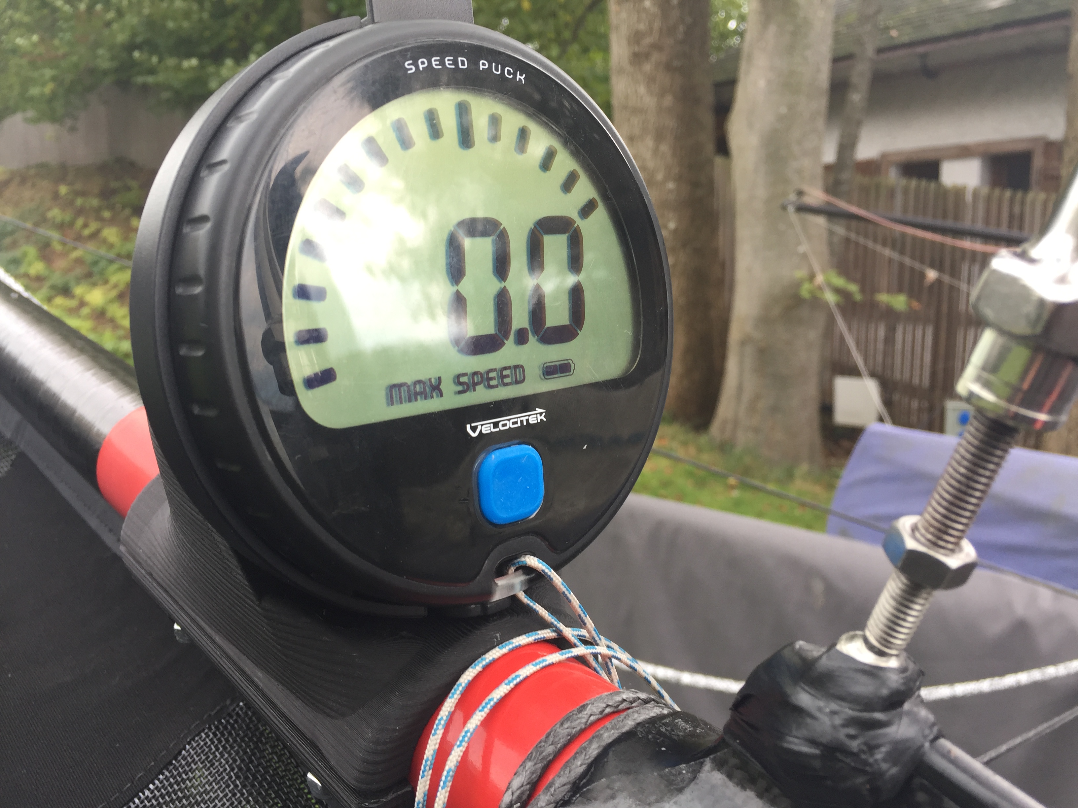
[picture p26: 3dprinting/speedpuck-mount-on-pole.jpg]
speedpuck mount


You print 2 pieces:
* the main mount (upper part)
* the clamp (lower part)

You need
* 6x 15-20mm stainless wood screws (max 3mm diameter, better 2.5mm)
* 4x 30mm M4 Hex bolts and Nyloc nuts - stainless

here is the Fusion 360 design:
[http://a360.co/2dl8z6m](http://a360.co/2dl8z6m) 

# Rig Tension Adjuster

As the Whisper catamaran rig should be tightened for every ride (and loosened thereafter) it is a bit tedious to use a wrench. Thus is designed this turning knob that can be used by hand. 

To make it a bit more robust I printed with ASA (UV and water resistant, as well as good mechanical properties --- I used FormFutura ApolloX) and apply at least 5 walls.

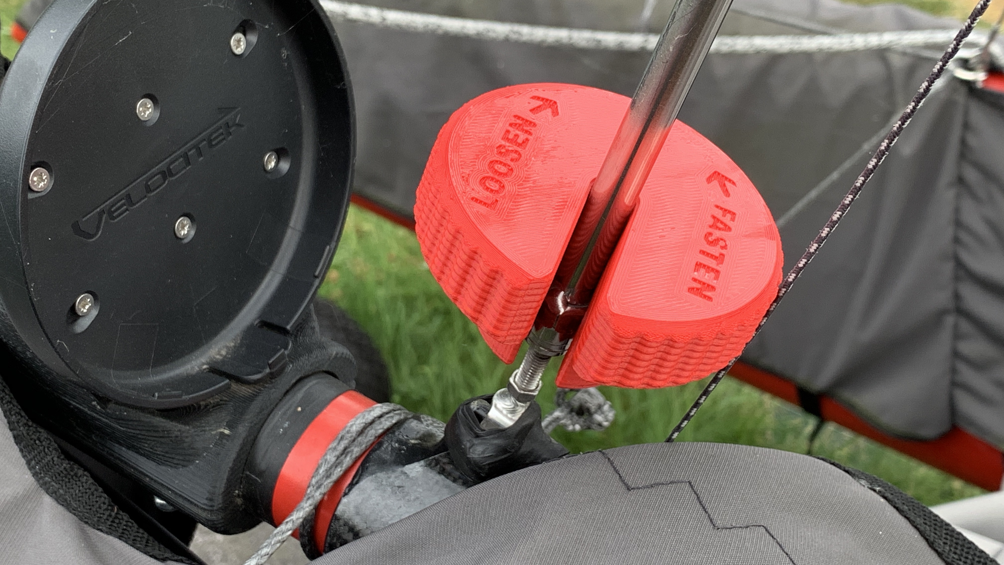
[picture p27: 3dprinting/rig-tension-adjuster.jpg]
rig tension adjuster


Fusion Design: [https://a360.co/2YBYY0c](https://a360.co/2YBYY0c)

# Boom Holder
Contributed by [Christian Witsch](https://www.youtube.com/channel/UChSlq1hUahmVQtAV6N_KJtA)

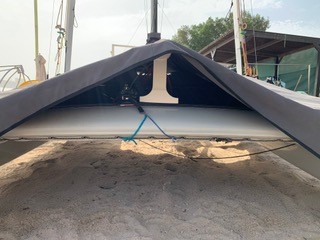
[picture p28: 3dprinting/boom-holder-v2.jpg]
boom holder


# Dolphin Striker Line Guide
Contributed by [Christian Witsch](https://www.youtube.com/channel/UChSlq1hUahmVQtAV6N_KJtA)

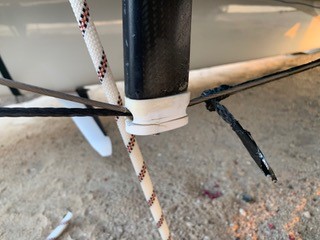
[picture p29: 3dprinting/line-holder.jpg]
line holder


* [guide](line-holder-guide.stl)
* [lid](line-holder-lid.stl)

# Material

My favorite material for such parts is [FormFutura ApolloX ASA](https://www.formfutura.com/shop/product/apollox-red-307?category=191). It is UV and water resistant, and has great mechanical properties. Easy to print with barely any warping as well. Make sure you print in 0.1mm layer height (or less) for better interlayer adhesian and use at least 5 walls.

 

# License
All models are licensed under __Creative Commons - Attribution - Non Commercial - Share Alike__

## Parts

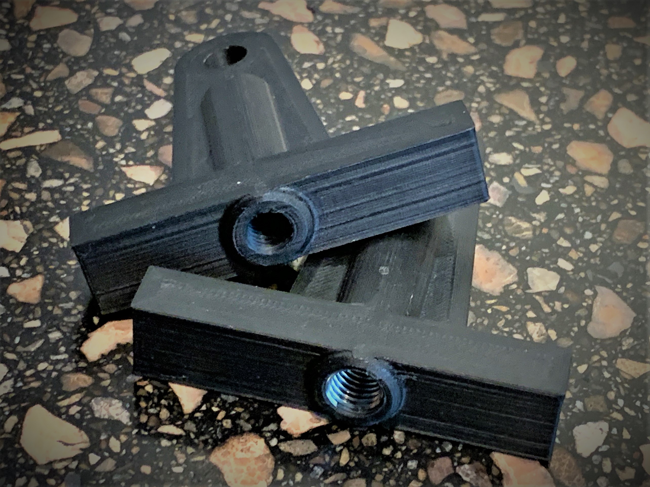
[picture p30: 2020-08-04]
3dprinting/T parts without and with helicoil insert.jpg

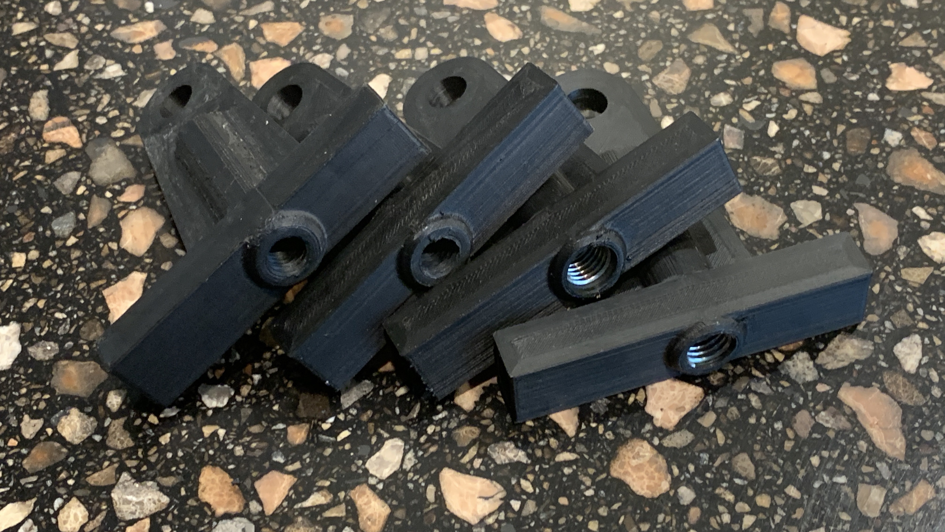
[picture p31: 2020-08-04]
3dprinting/4 pieces T parts.jpg

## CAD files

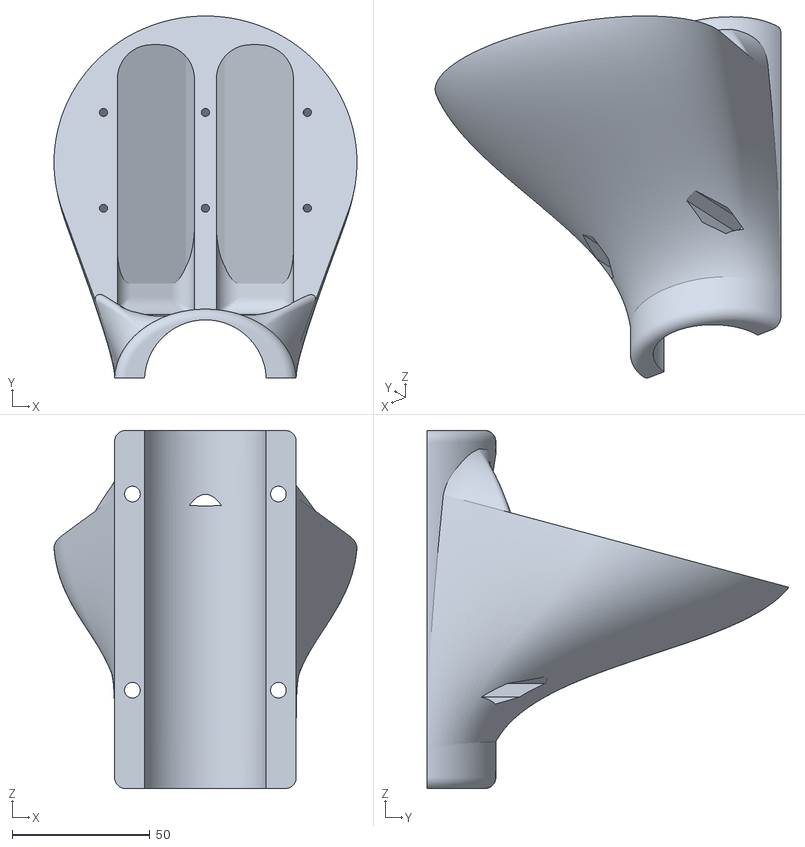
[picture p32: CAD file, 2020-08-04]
3dprinting/VelocitekHolderWhisperV4main.stl
110.0 x 131.4 x 130.0

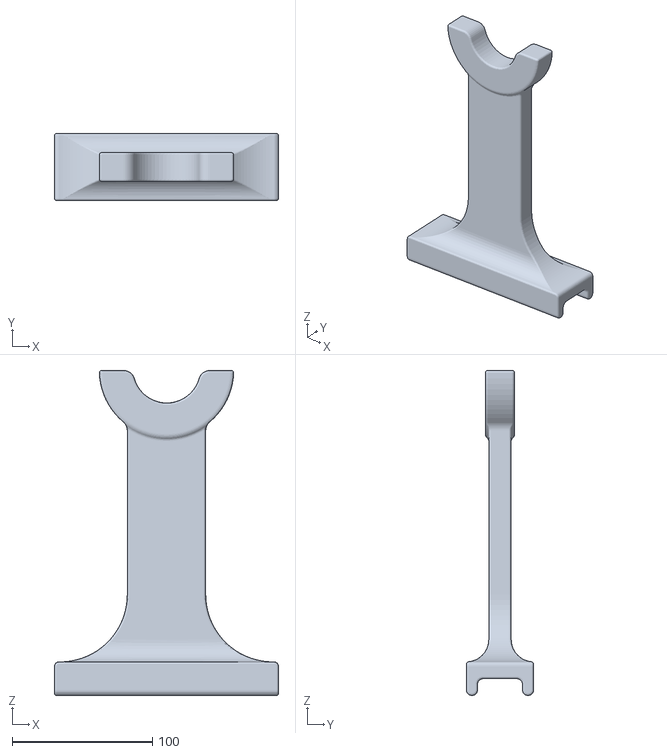
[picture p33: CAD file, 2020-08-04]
3dprinting/boom holder v2.stl
160.0 x 48.0 x 232.0

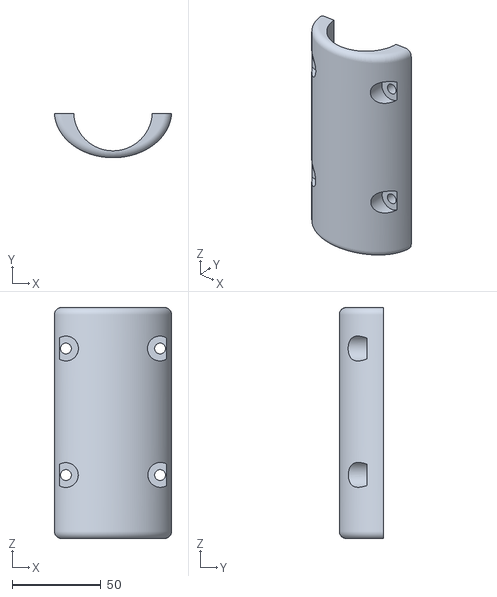
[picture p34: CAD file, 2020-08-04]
3dprinting/VelocitekHolderWhisperV4clamp.stl
66.0 x 25.0 x 130.0

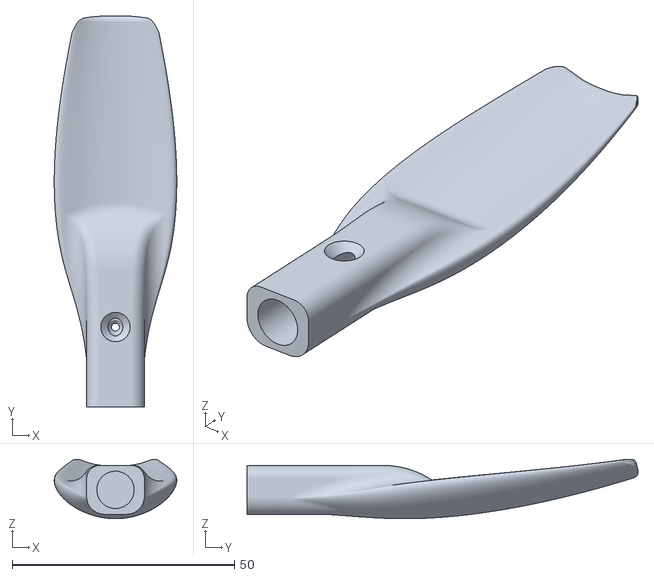
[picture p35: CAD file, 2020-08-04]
3dprinting/wand paddle.stl
27.6 x 88.0 x 13.4

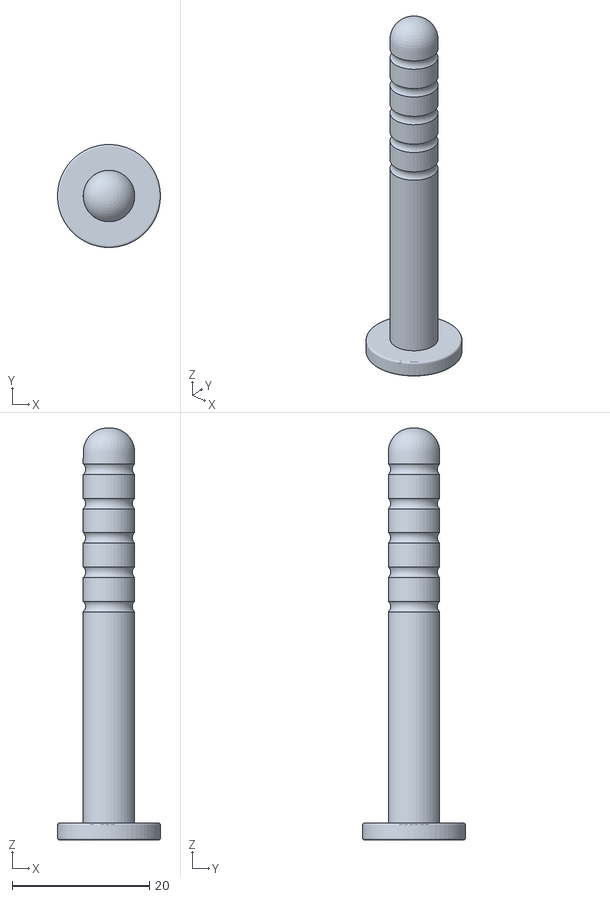
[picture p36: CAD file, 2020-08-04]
3dprinting/ride-height-pin.stl
15.0 x 15.0 x 60.0

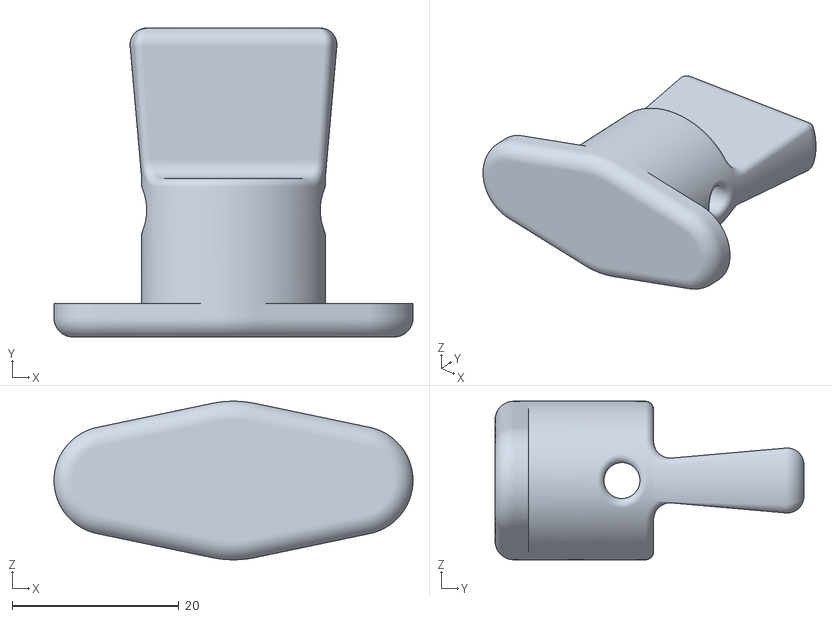
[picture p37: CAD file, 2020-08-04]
3dprinting/WhisperRudderRopeStraightTwister.stl
43.0 x 37.0 x 19.0

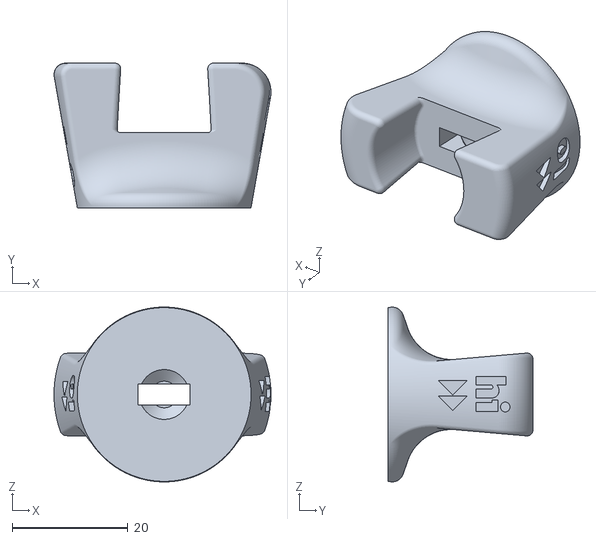
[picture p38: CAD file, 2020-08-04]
3dprinting/ride height knob.stl
37.5 x 25.0 x 30.2

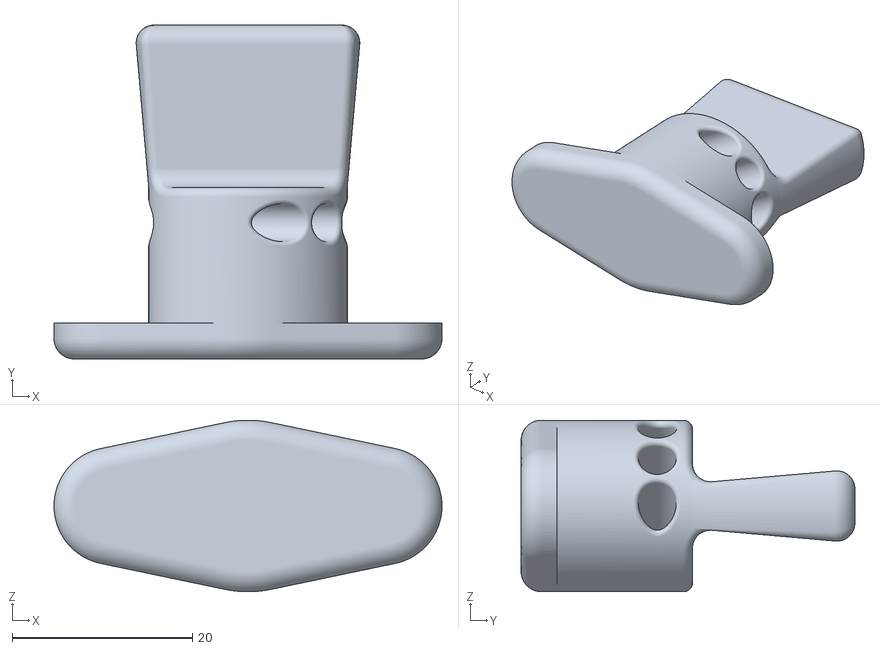
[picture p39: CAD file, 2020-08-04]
3dprinting/whisper3mmropetwister.stl
43.0 x 37.0 x 19.0

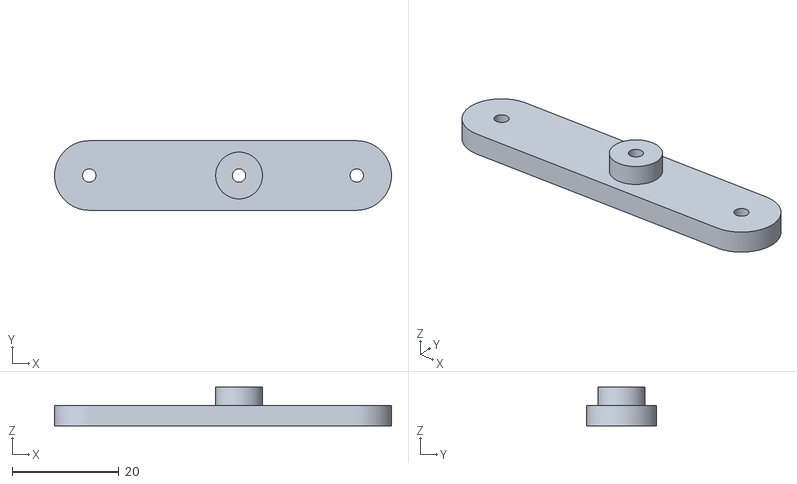
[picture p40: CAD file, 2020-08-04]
3dprinting/wand lever back 8.75mm.stl
63.0 x 13.0 x 7.20

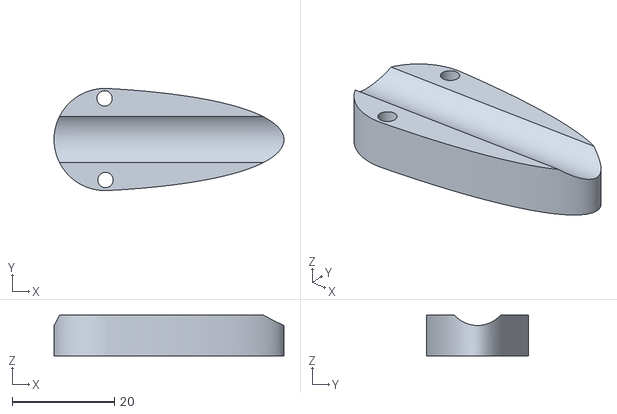
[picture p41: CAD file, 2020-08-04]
3dprinting/line-holder-lid.stl
45.0 x 20.0 x 8.00

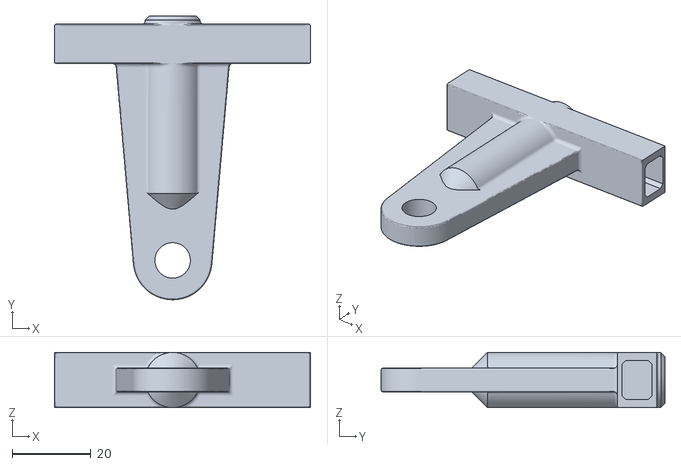
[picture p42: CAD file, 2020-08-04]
3dprinting/Whisper Ride Height T Helicoil M8x1.25x3D.stl
65.0 x 72.0 x 14.0

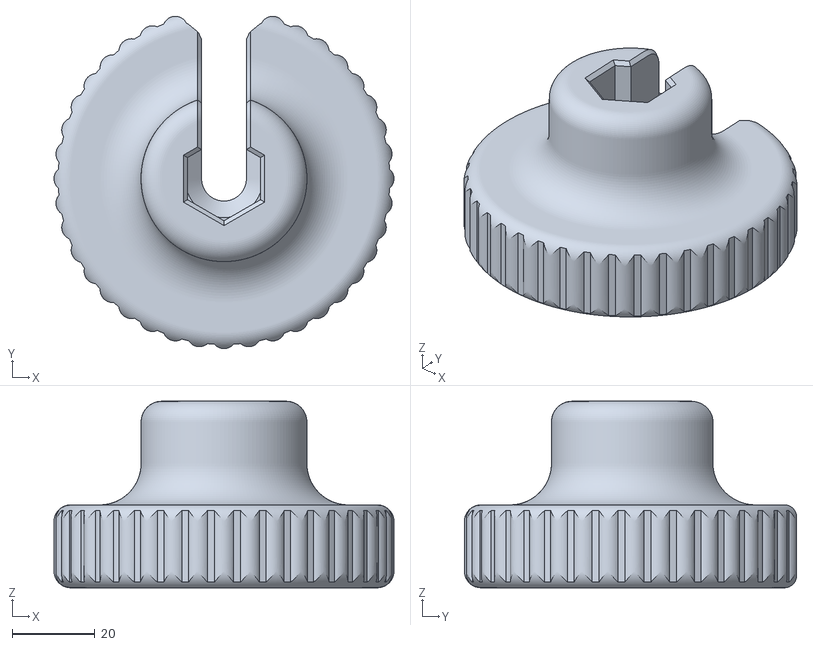
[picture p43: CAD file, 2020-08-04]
3dprinting/StrikerHandNut.stl
82.0 x 80.1 x 45.0

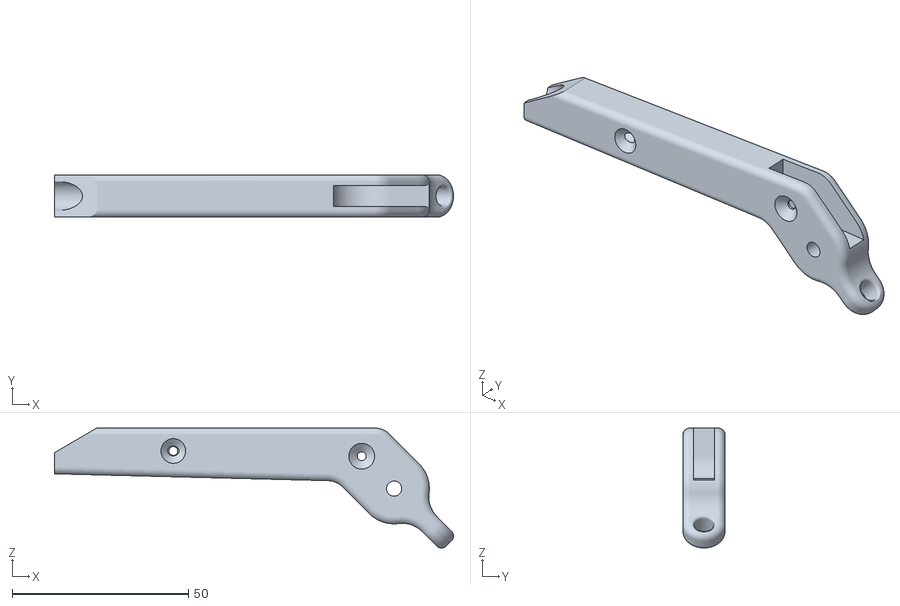
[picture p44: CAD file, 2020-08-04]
3dprinting/wand arm.stl
113.2 x 12.0 x 34.0

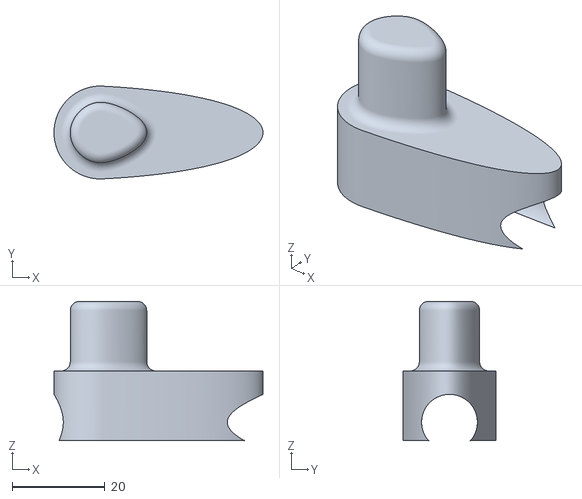
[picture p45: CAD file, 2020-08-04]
3dprinting/line-holder-guide.stl
45.0 x 20.0 x 30.0

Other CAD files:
3dprinting/Whisper Ride Height T.stl
3dprinting/wand lever front 8.75mm.stl
3dprinting/whisper-ride-height-T-with-threads.stl
3dprinting/wand skimmer screw sideways.stl
3dprinting/line holder parts.f3d
3dprinting/wand arm screw aft side.stl
3dprinting/wand arm twosidedwandscrew.stl
3dprinting/wand paddle.f3d
3dprinting/wand skimmer screw aft.stl

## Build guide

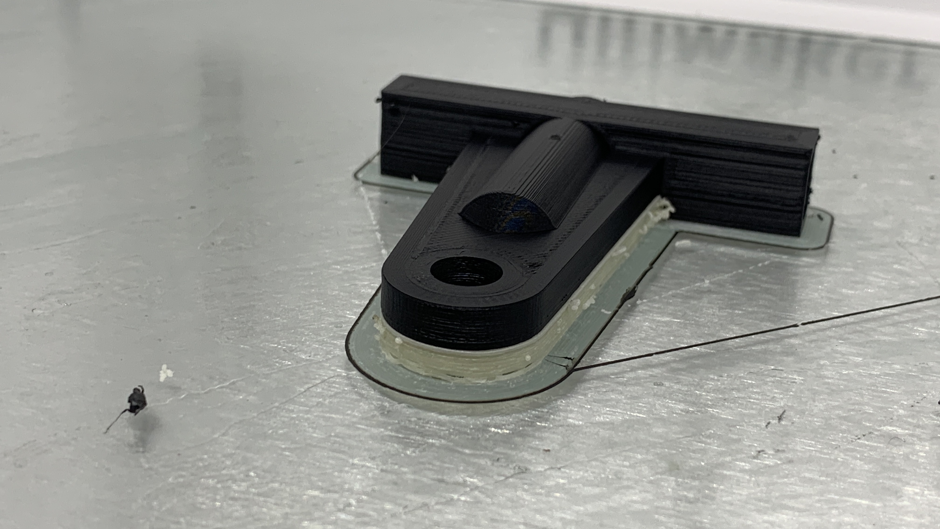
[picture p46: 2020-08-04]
3dprinting/printed T part with supports.jpg

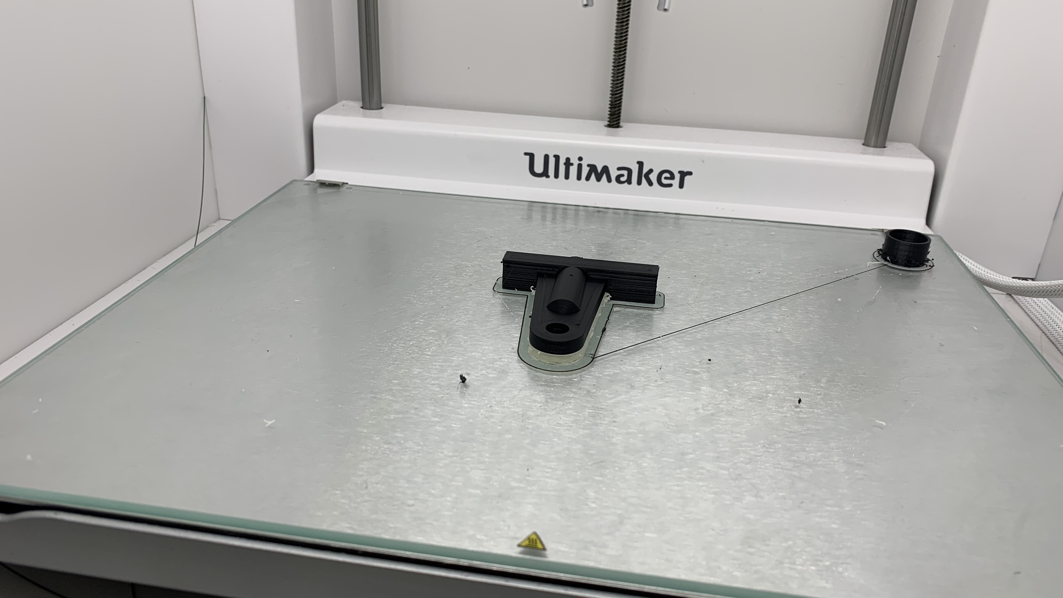
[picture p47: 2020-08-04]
3dprinting/printed T part ApolloX on Helios PVA.jpg

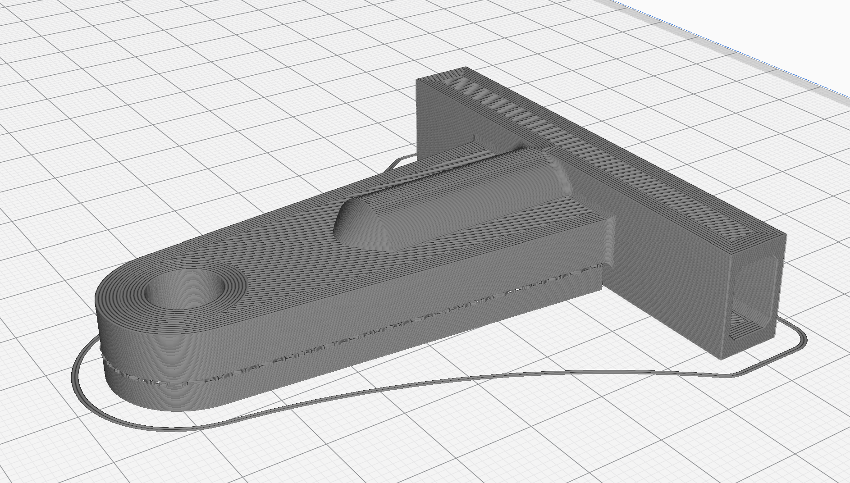
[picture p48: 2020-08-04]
3dprinting/Whisper Ride Height T Print Horizontally for strength.png

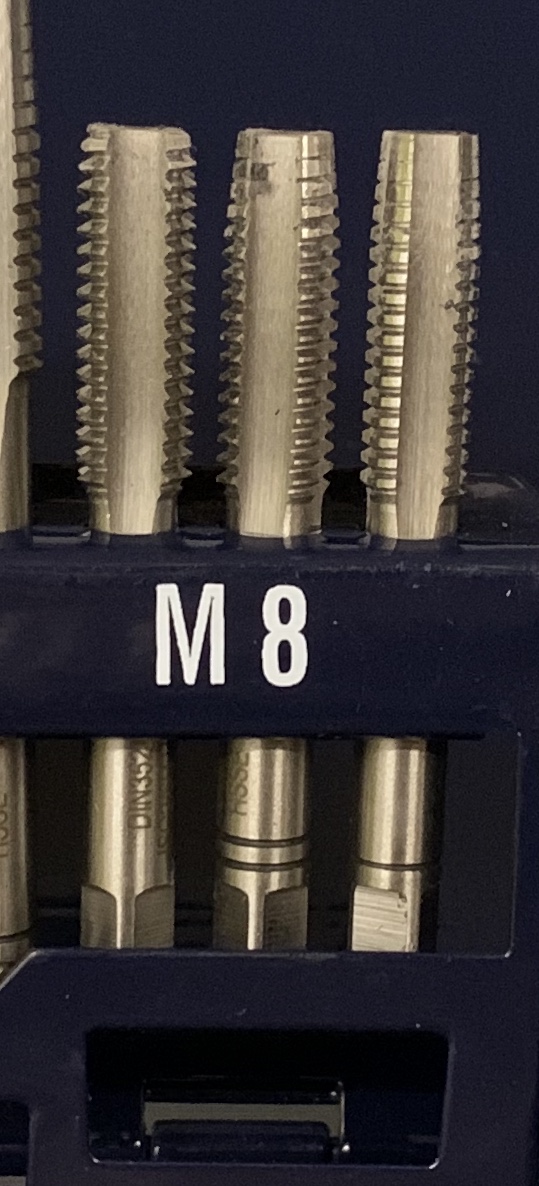
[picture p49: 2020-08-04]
3dprinting/M8 thread makers.jpg

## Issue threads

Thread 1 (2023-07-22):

Thank you so much!

mikemeixner, 2023-07-22:
Hello and thank you for all the info you posted regarding the Whisper. I also own a Whisper and found the information you provide very useful. I recently lost a wand and used your 3D files to print the paddle and wand arm. I'm currently looking for a distributor for the CF 8mm rods that are willing to ship to Canada.

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

flyinggorilla, 2023-07-23:
Awesome!

Just one suggestion, in case you find the wand arm breaking. As to your picture, the print was dont from the rod-opening upwards to the bungee hole. this causes most force to be held by 3D print interlayer adhesion, what is the weak spot of FFF 3D printing. So if you find it is breaking, I suggest to print it layed down with supports. It works with support of same material (and using a drill and pliers to remove supports) or dissolvable support. When you lay down the wand arm, the forces are in direction of extruded material, what makes it stronger.

Closed 2023-07-23.

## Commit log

2017-07-10 rudder holder v2
2017-08-26 adding untight hull fixing
2018-08-11 updating for footstraps and pressure compensation
2018-08-26 updated rig tension
2020-08-04 added 3d printed parts and models
    [Pin to measure hight adjustment for the Whisper foils v1.stl, StrikerHandNut.stl, Whisper Ride Height T Helicoil M8x1.25x3D.stl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]
2020-08-04 completed first set of 3d printing parts upload
    [VelocitekHolderWhisperV4clamp.stl, VelocitekHolderWhisperV4main.stl]
2020-08-04 added community provided boom holder
    [boom holder v2.stl]
2020-08-04 github can view stl files
2020-08-04 stl issues
2020-08-04 fix stl
    [WhisperRudderRopeStraightTwister.stl]
2020-08-04 fixing stl links
2020-08-04 add community contributions
    [WhisperRudderRopeWedge.stl, WhisperRudderRopeWedgeShort.stl, line-holder-guide.stl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]
